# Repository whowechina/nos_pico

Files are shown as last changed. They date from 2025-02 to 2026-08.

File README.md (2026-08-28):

# Nos Pico - Nostalgia Style Mini Controller
[点这里可以切换到中文版](README_CN.md)

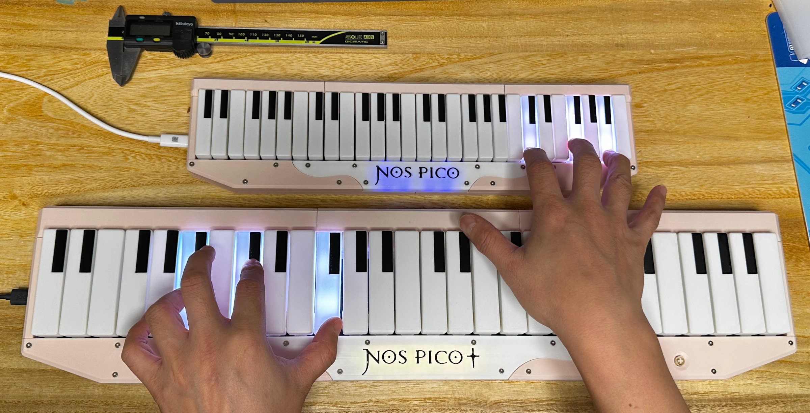
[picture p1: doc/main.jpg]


Currently there're two sizes of Nos Pico. Nos Pico is the small one, suitable for 15 to 17 inch monitors. Nos Pico+ is the larger one, suitable for 24 to 27 inch monitors. There're no differences except the size.

Features:
* All 3D printed parts.
* Velocity sensitive.
* RGB key lights.
* Works as MIDI keyboard.
* HID lights.
* 4 extra programmable buttons.

Thanks to many respectful guys/companies who made their tools or materials free or open source (KiCad, OnShape, InkScape, Raspberry things).

Special thanks to community projects and developers.
And also these projects:
* RP_Silicon_KiCad: https://github.com/HeadBoffin/RP_Silicon_KiCad
* Type-C: https://github.com/ai03-2725/Type-C.pretty

## My Other Projects
You can check out my other cool projects.

               


* Popn Pico: https://github.com/whowechina/popn_pico
* IIDX Pico: https://github.com/whowechina/iidx_pico
* Chu Pico: https://github.com/whowechina/chu_pico
* Mai Pico: https://github.com/whowechina/mai_pico
* Diva Pico: https://github.com/whowechina/diva_pico
* AIC Pico: https://github.com/whowechina/aic_pico
* Groove Pico: https://github.com/whowechina/groove_pico
* Geki Pico: https://github.com/whowechina/geki_pico
* Musec Pico: https://github.com/whowechina/musec_pico
* Ju Pico: https://github.com/whowechina/ju_pico
* Bishi Pico: https://github.com/whowechina/bishi_pico
* Nos Pico: https://github.com/whowechina/nos_pico
* Voltex Pico: https://github.com/whowechina/voltex_pico
* Chord Pico: https://github.com/whowechina/chord_pico
* Dance Pico: https://github.com/whowechina/dance_pico
* Arcade Pico: https://github.com/whowechina/arcade_pico

## **Disclaimer** ##
I made this project in my personal time with no financial benefit or sponsorship. I will continue to improve the project. I have done my best to ensure that everything is accurate and functional, there's always a chance that mistakes may occur. I cannot be held responsible for any loss of your time or money that may result from using this open source project. Thank you for your understanding.

## About the License
It's CC-NC. So DIY for yourself and for your friend, don't make money from it. And plagiarism that doesn’t even dare to mention the original author is not acceptable. Please note that pooling orders and group buying for raw materials is acceptable.Selling any leftover components at cost (without profit) is also acceptable.

If you're interested in buying from me, or for commercial use, please contact me (Discord, QQ group, Goofish).
* My Discord Invitation: https://discord.gg/M8f2PPQFEA
* QQ Group: 854535476
* Goofish: whowe12345

## HOW TO BUILD
### PCB and Components
* Go JLCPCB or any PCB vendor you like, make order with the gerber zip files (latest `Production\PCB\nos_pico_xxx.zip` for Nos Pico, or `Production\PCB\nos_plus_xxx.zip` for Nos Pico+), regular FR-4 board, black color, **1.6mm** thickness.

* 1x Rasberry Pico Pi Pico or pin-to-pin compatible clones, those with type-C port are strongly recommended.  
  https://www.raspberrypi.com/products/raspberry-pi-pico
* 1x USB Type-C socket (918-418K2023S40001 or KH-TYPE-C-16P)

* 1x ADG732BSUZ (TQFP48) analog multiplexer.  
  https://www.analog.com/en/products/adg732.html
* 1x MBR120VLSFT1G Schottky diode (SOD-123), or any SOD-123 **Schottky** diode with 1A or more current rating.
* 20x to 30x 0603 0.1uF (0.1~1uF all fine) capacitors.
* 3x 0603 5.1kohm resistors, 2 for USB and 1 for signal divider.
* 1x 0603 2kohm resistor for signal divider.
* 28x SS49E linear Hall effect sensors (SOT23).
* 1x Small 3V to 5V DC-DC step up or up-down converter. Make sure its output is 5V and input range covers 3.3V. If the one you get has different pinout, you need to hand wire it. If you don't see the footprint in the PCB, that means it's removed from newer revisions.  
  https://www.dfrobot.com/product-1766.html

* for Nos Pico only:
  * 56x WS2812B-4020 RGB LEDs (side facing)
  * 6x WS2812B-3528 RGB LEDs.
  * 4x HDK KSMC614A or Alps SKRGASD010 switches (6mm\*6mm\*9.5mm).  
    https://www.hdk.co.jp/pdf/spj/spj_ksmc614a.pdf  
    https://www.mouser.com/datasheet/2/15/alps_s_a0002902192_1-2258679.pdf
    
* for Nos Pico+ only:
  * 62x WS2812B-3528 RGB LEDs.
  * 4x Kailh Box Cream Pro switches.  
    https://www.kailh.net/products/kailh-box-cream-pro-switch-set

* Note: in newer revisions, the DC/DC is removed, use the following components instead.
  * 1x TPS7A2042PDBVR (4.2V) or LP5907MFX-4.5 (4.5V) LDO (SOT23-5), (U7).  
    https://www.ti.com/product/TPS7A20/part-details/TPS7A2042PDBVR
  * 1x LM4040 3.0V Shunt Voltage Reference, in SOT23-3 (U6). There're many models; make sure it's 3.0V and in an SOT23-3 package.
  * R1 and R2 are 2Kohm and 5.1Kohm 0603 resistors, respectively.

* This is how Nos Pico looks after soldering.  
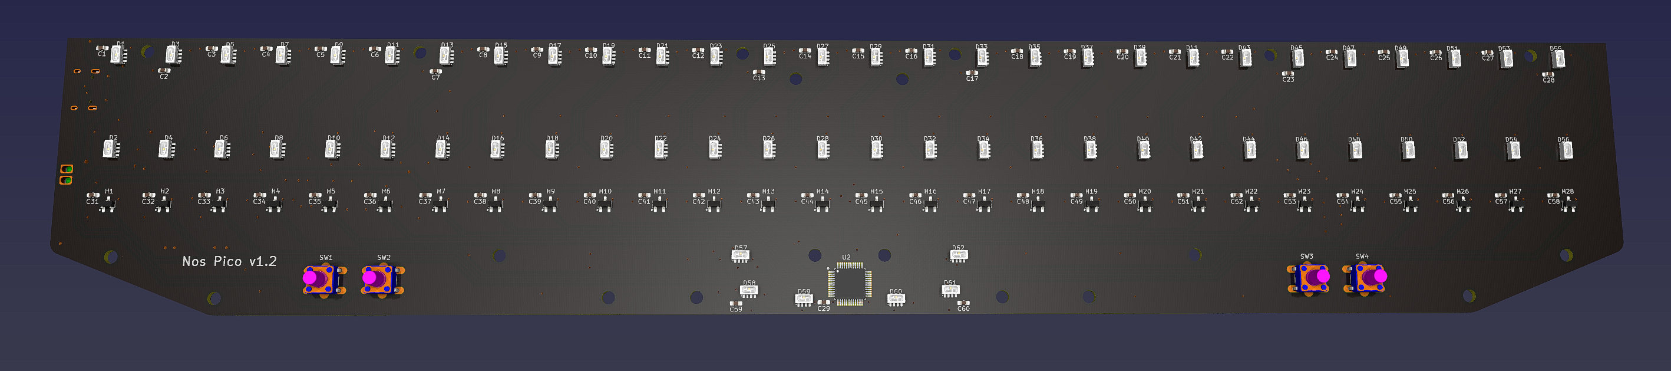
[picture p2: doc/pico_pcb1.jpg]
    
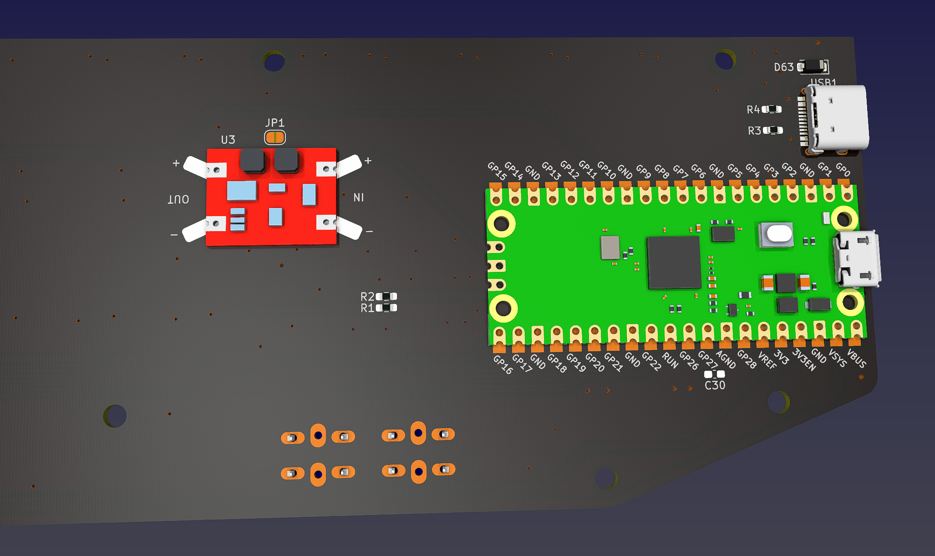
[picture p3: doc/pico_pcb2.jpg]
  

* This is how Nos Pico+ looks after soldering.  
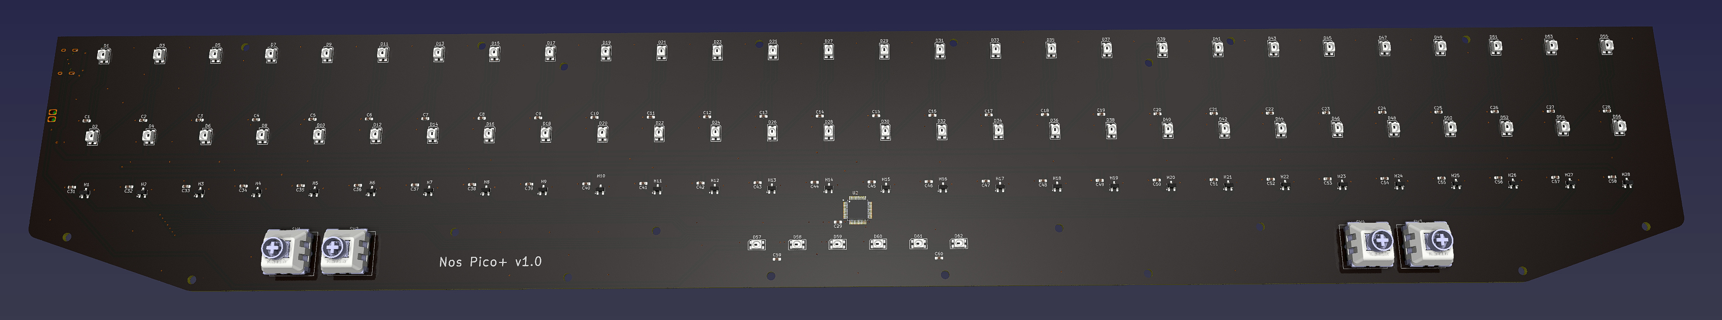
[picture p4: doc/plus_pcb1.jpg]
    
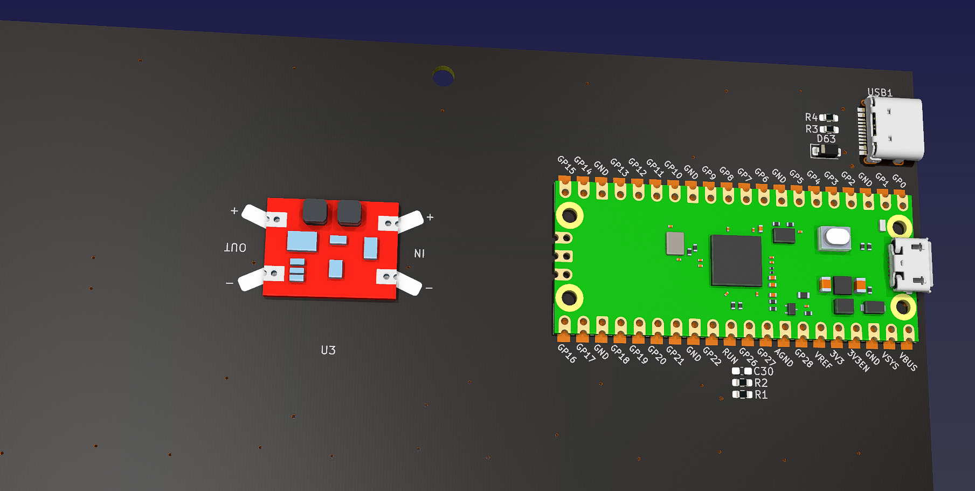
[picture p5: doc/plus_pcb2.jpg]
  

### Notes
1. About the 2 USB holes, you decide whether to solder them or not.   
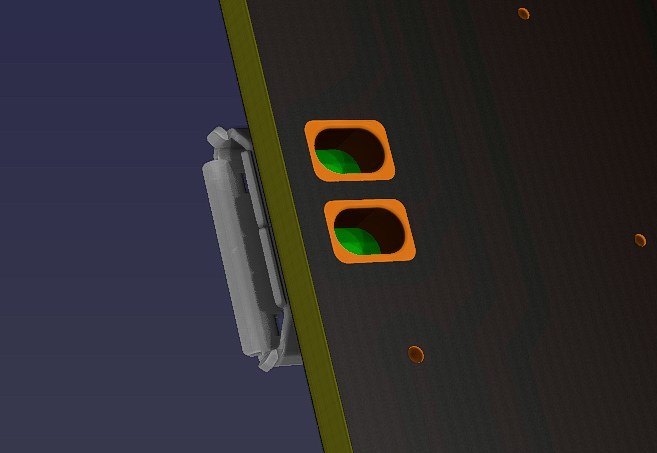
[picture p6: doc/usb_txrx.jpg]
   

   * If you solder these 2 hole pins.
     * Pros: ether USB ports can be used for host communication; if your pico has a micro USB port, now you'll have a Type-C port and a micro USB port.
     * Cons: if one port is for host communication, the other port can use for power supply, but only from power bank or charger, not from a USB data port.

   * Or you don't solder them (and also better use thin tape to cover the pins on Pi Pico).
     * Pros: only the port from Pi Pico can be used for host communication, the other port can only be used for power supply.
     * Cons: the power supply port can connect to any USB port, inluding USB data ports, power banks or chargers.

2. There're so many capacitors for de-coupling. You don't need to solder them all. You can solder some of them, just distribute them evenly. The one near the multiplexer is a must.

3. Leave C30 un-soldered.

### Test the PCB
* You can test the PCB now, put the firmware in.
* Very likely all key LEDs will light up in white.
* Logo LEDs will slowly change color.
* Nos Pico should be recognized as a USB HID device, here's the test page.  
  https://greggman.github.io/html5-gamepad-test/
* The test page responds to the 4 button switches.
* Use the terminal tool to connect to Nos Pico's command line interface.
  https://googlechromelabs.github.io/serial-terminal/
* Keep the PCB away from magnetic field, such as speakers or motors and execute `calibrate origin`. All values should be similar and near 2200.
* If you notice strange values, you need to check the soldering of the muxiplexer and corresponding hall effect sensor.

### 3D Printing
#### Printing parameters  
* PLA or PETG.
* Layer height: 0.2mm
* Wall: 2 to 3.
* Support: No, unless explicitly mentioned.
* Files are always in milimeter unit, not inch.

#### Parts
* All files are in `Production\3DPrint` folder.
* File names started with `Nos Pico -` are for Nos Pico, and `Nos Pico+ -` are for Nos Pico+.

* Keys: `Key.3mf`. Print 28 keys, 8 all-white, and 20 white-with-black tops (with "black key"). You need multi-color printing for the keys, or you need to manually paint the black part.  
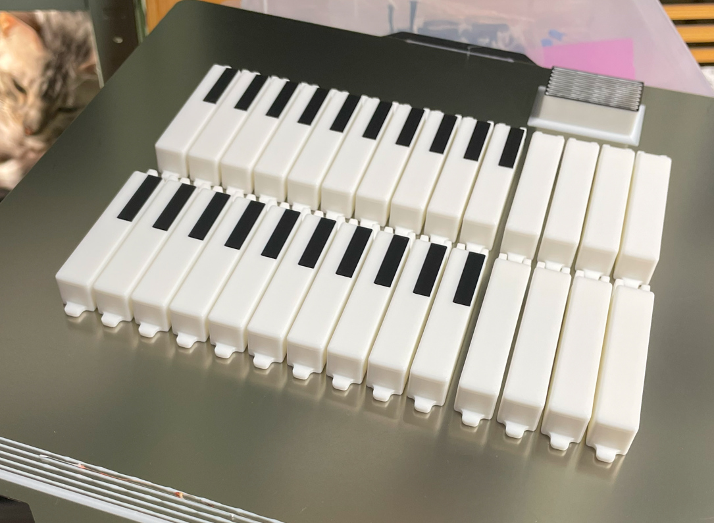
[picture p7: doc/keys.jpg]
  
* Base: `Base_*.stl`, all in light apricot color.
* Rear: `Rear_*.stl`, all in light apricot color. Make the side with the screws as the bottom and **enable support**.
* Support: `Support_*.stl`, Left and Right are in light apricot color and Center is in white color.
* Panel: `Panel_*.stl`, Left and Right are in light apricot color. The Center is in white color with the black logo on top. You can use multi-color to print it or paint it manually.

### Assembly
#### Other components needed
Please note that the quantities of the screws are approximate.

* 10x M3\*6mm screws for the PCB to the base parts.
* 20x M3\*8mm screws for support parts to the base parts.
* 16x M3\*8mm screws for rear parts to the base parts.
* 20x M2\*8mm countersunk screws for the panels to the support parts.
* Some 2.5mm~3mm thick self-adhesive foam tape (Poron or EVA).
* Some 1mm~1.5mm thick self-adhesive foam tape (Poron or EVA).

* 28x 0.4\*5\*10\*6N (0.4mm wire diameter, 5mm outer diameter, 10mm free length, 6 turns) springs.
* Some white silicone adhesive, such as K-704 silicone industrial adhesive.

* Some 10mm diameter silicone self-adhesive anti-slip pads.  

* For Nos Pico only.
  * 1x 2mm\*361mm stainless steel wire shaft.
  * 28x 2mm\*2mm axial magnetized cylinder magnets (2mm diameter, 2mm height).

* For Nos Pico+ only.
  * 1x 2mm\*573mm stainless steel wire shaft.
  * 28x 3mm\*2mm axial magnetized cylinder magnets (3mm diameter, 2mm height).

#### Steps
Please note that the pictures in this section are mixed with Nos Pico and Nos Pico+, some are even from prototype. But the assembly steps are the same. So ignore the differences in some details.

1. Use the M3\*6mm screws to fix the PCB to the base part.  
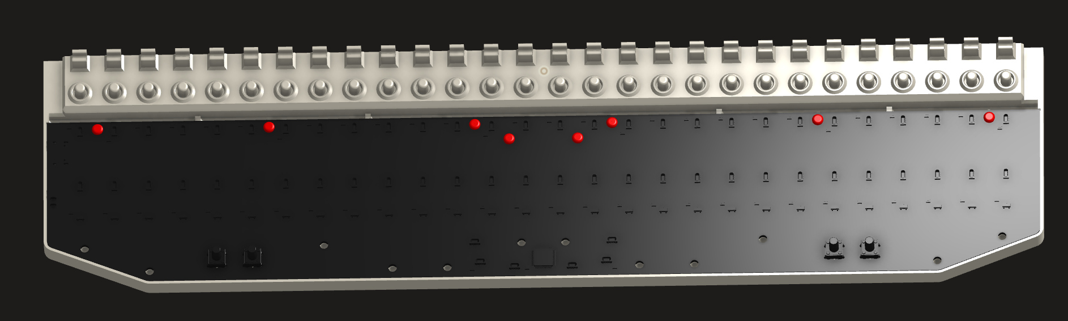
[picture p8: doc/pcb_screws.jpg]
   
2. Apply the 2.5mm thick foam tape on PCB, right below the hall effect sensors. It damps the key press noise. 3mm width is recommended for Nos Pico, and 5mm width is recommended for Nos Pico+.  
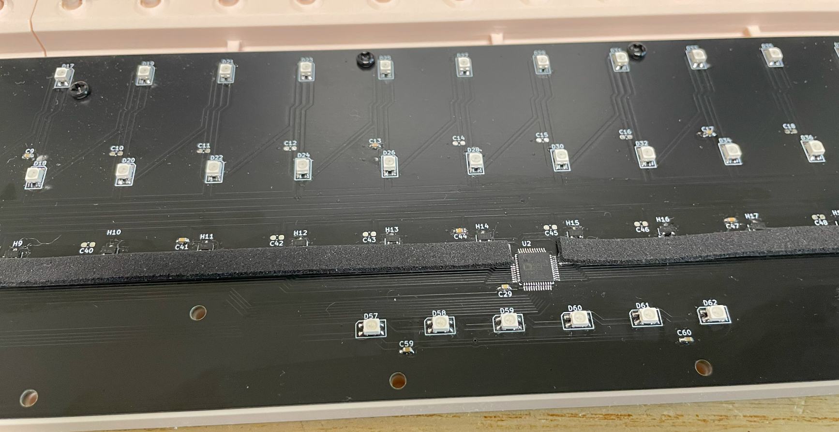
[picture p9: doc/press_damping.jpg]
   
3. Use the M3*8mm screws to fix the support parts to the base part.  
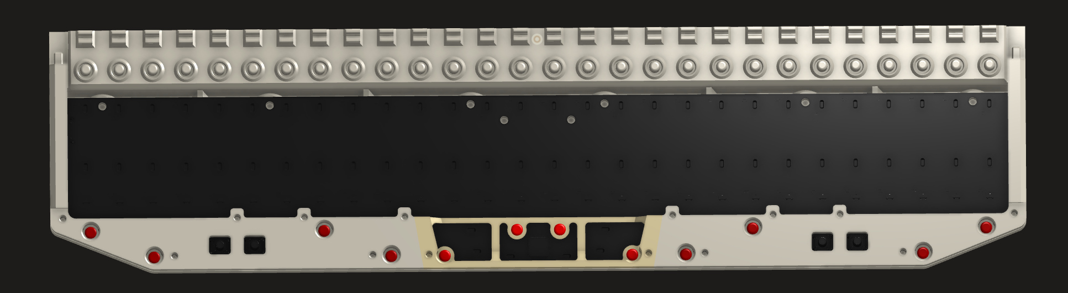
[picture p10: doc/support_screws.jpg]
   
4. Insert the steel shafts into keys and install them into the base parts. Please note the key arrangements.  
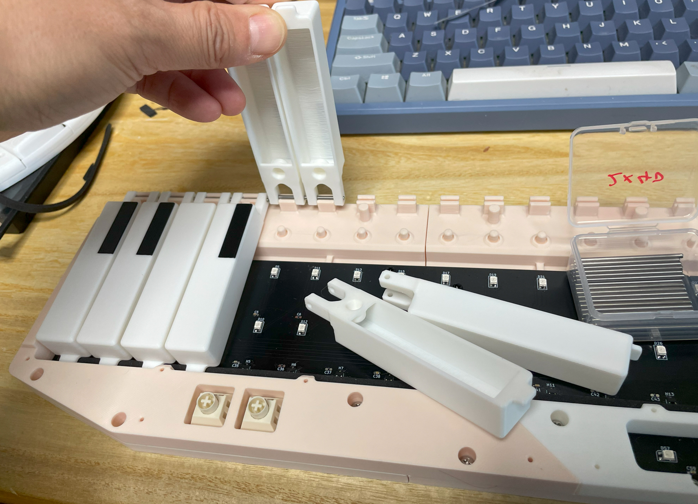
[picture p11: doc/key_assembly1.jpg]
     
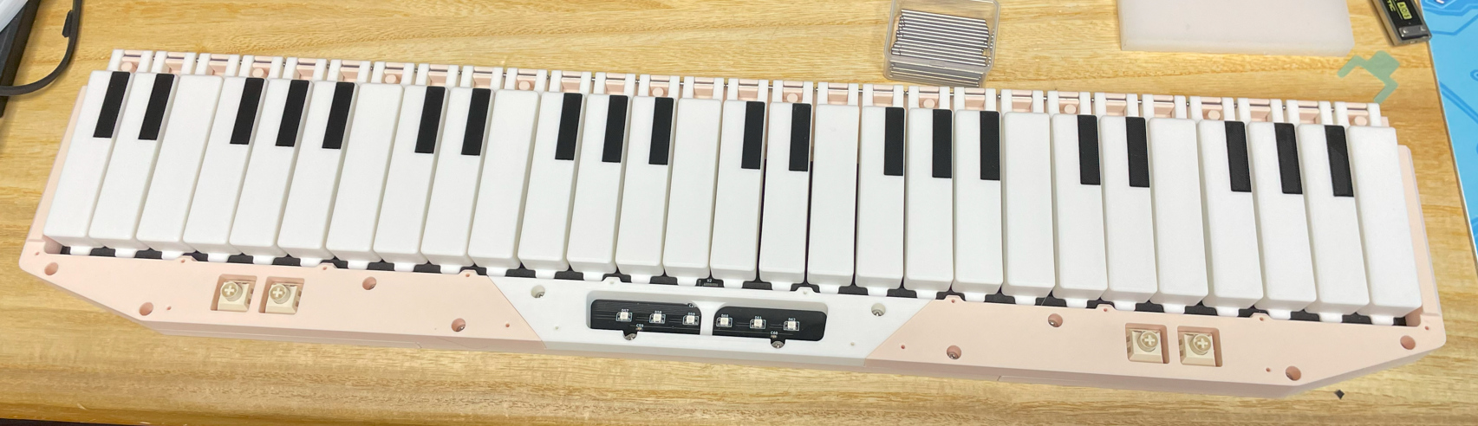
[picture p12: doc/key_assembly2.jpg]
   
5. Rotate the keys to the other side to insert the magnets into the keys. Cylinder magnets should be placed vertically. You need some glue or silicone adhesive to fix them in place.
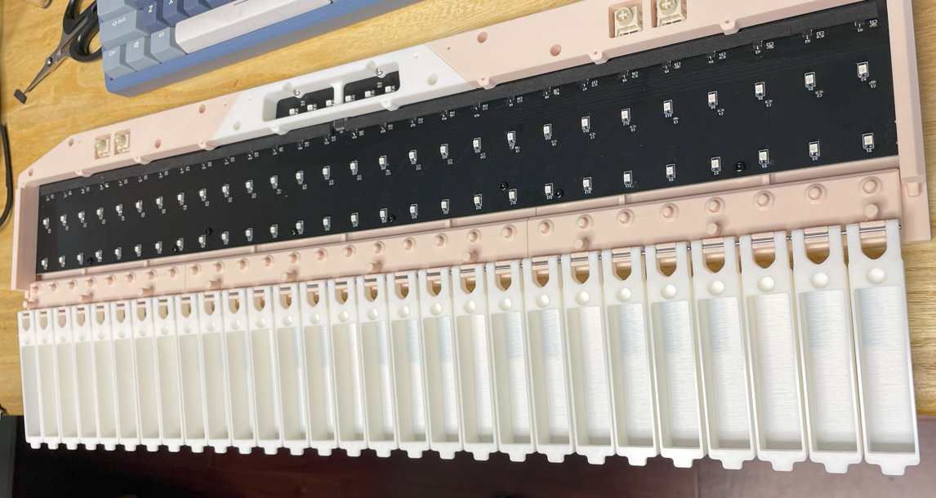
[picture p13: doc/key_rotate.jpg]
     
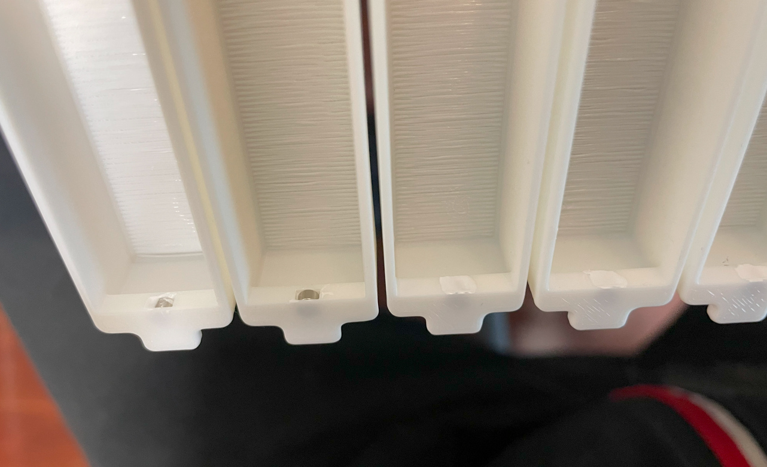
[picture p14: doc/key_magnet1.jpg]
     
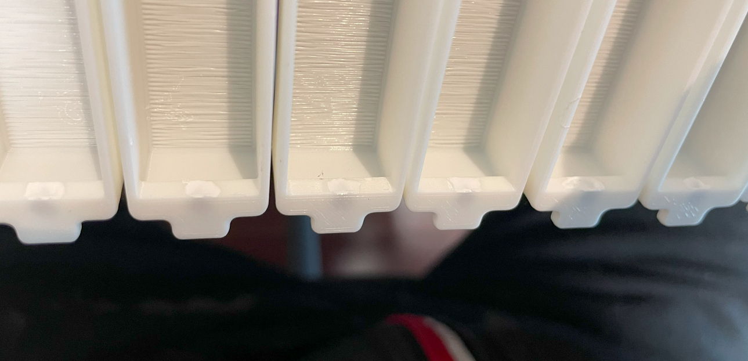
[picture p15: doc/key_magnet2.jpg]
   
6. Install the springs on the base parts, and rotate the keys onto them.
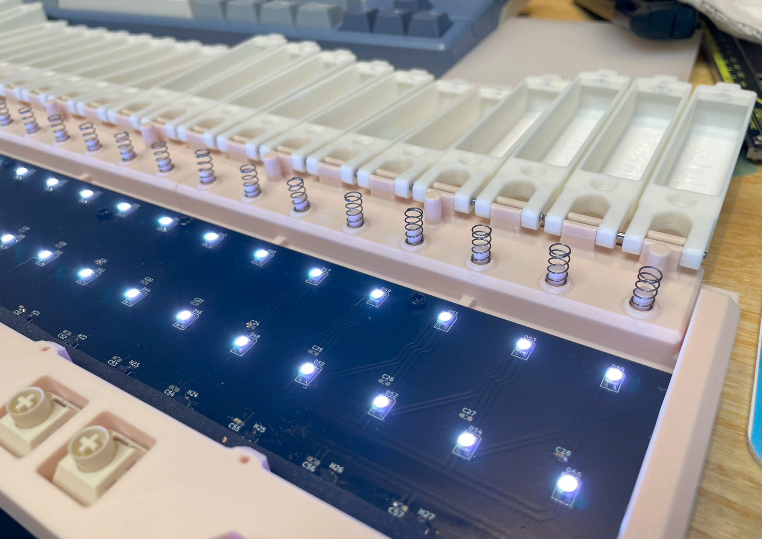
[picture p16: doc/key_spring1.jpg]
     
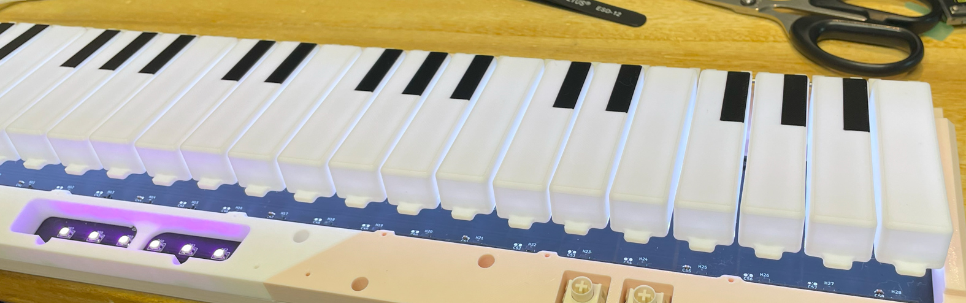
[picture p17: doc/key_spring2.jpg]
   
7. Now we temporarily calibrate and test the keys use `calibrate travel` command. Leave the keys un-pressed before executing the command, 1 second later, gently press down all the keys (not neccessarily all of them simultanously, just to cover them all). After calibration, keys are ready for play. You can use some MIDI software to test the keys. If all keys work fine, you can proceed to the next step. If not, you need to check the soldering of the hall effect sensors and the multiplexer.  
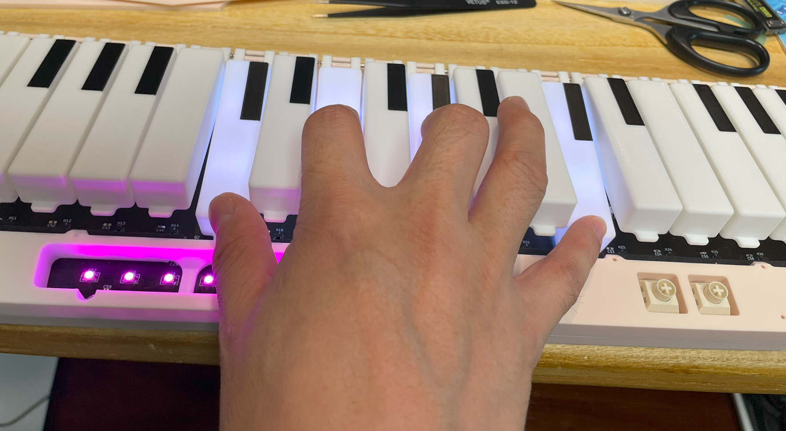
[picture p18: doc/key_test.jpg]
   
8. Apply the 1mm thick foam tape on the edge of the panel parts. It damps the key release noise.  
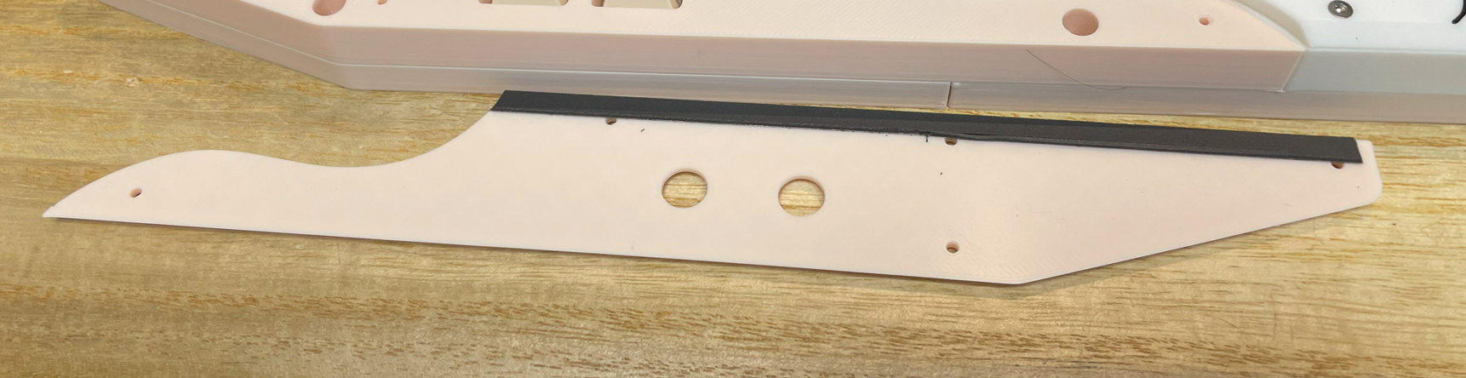
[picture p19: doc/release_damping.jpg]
   
9.  Use the M2*8mm countersunk screws to fix the panel parts to the support parts.  
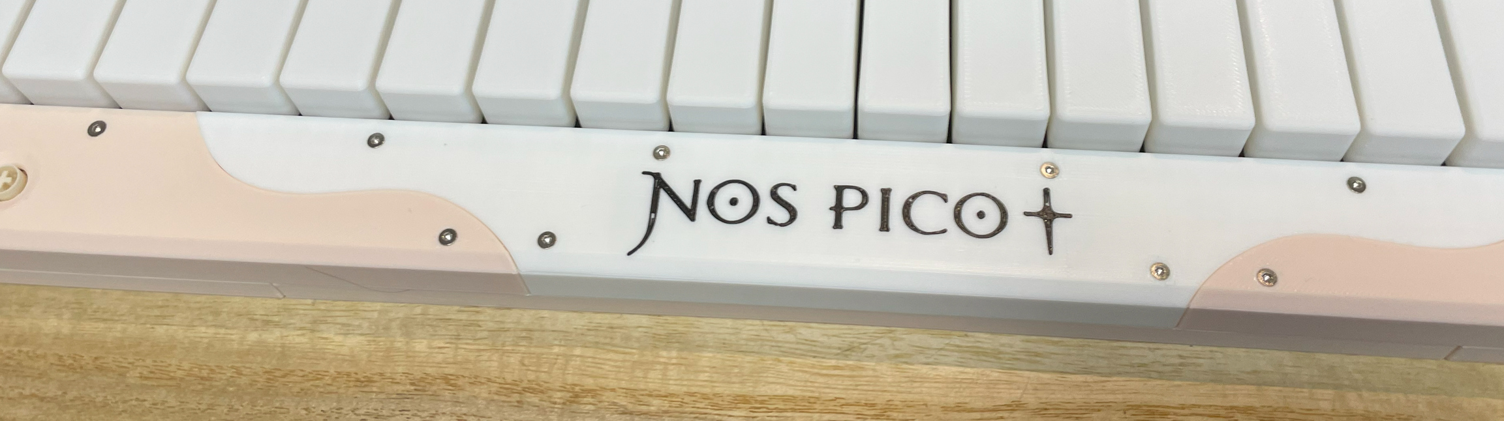
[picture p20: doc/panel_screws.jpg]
    
10. Use the M3*10mm screws to fix the rear parts to the base parts. Please note that left and right rear parts have a shaft limit slot, which is blocked by thin walls working as print support, you need to cut them open.  
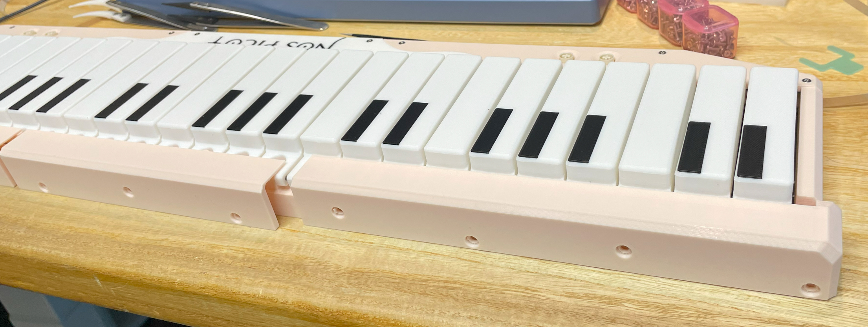
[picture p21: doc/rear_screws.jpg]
    
11. Now calibrate the key travel again use `calibrate travel` command, don't forget to gently press down all the keys 1 second after executing the command.
12. Apply the silicone self-adhesive anti-slip pads on the bottom of the base parts.  
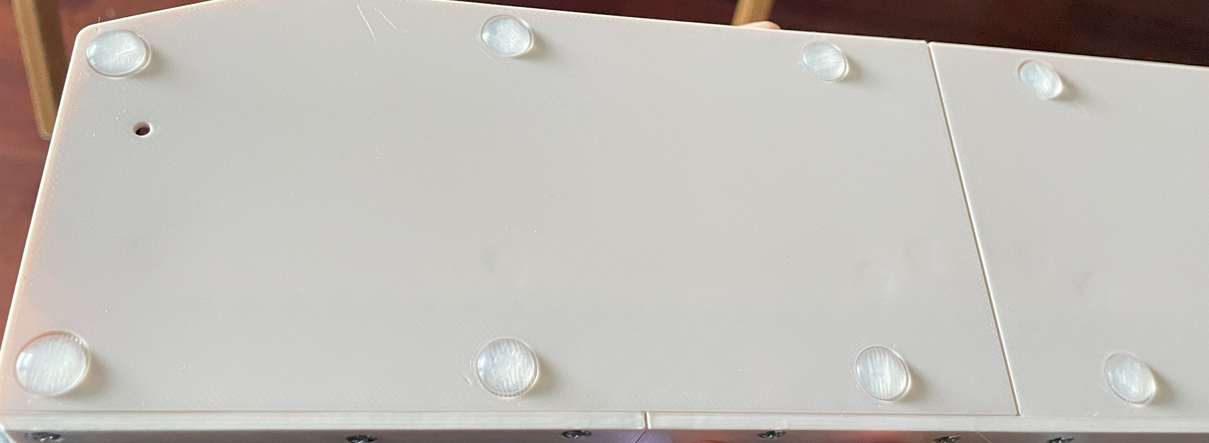
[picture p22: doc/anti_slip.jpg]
    
13. Congratulations, you finished!
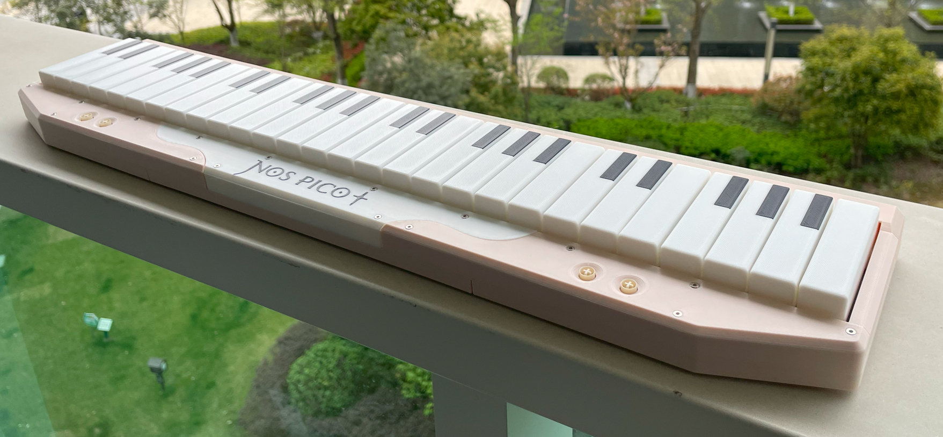
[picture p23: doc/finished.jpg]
    

#### Caution
* Don't use `calibrate origin` command after the assembly. It can only be used when there's no magnets installed.
* Screws are easy to break 3D printed parts. So don't screw them too fast or too tight. When you notice the resistance suddenly increases, stop immediately.

### Firmware
* UF2 file is in `Production\Firmware` folder.
* For the new build, hold the BOOTSEL button while connect the USB to a PC, there will be a disk named "RPI-RP2" showed up. Drag the UF2 firmware binary file into it. That's it. Note that there's a small hole on the bottom side of the Nos Pico, aligned with the BOOTSEL button.
* If it's already running Nos Pico firmware, you can either use "update" in command line or hold down left 2 buttons while connecting to USB to enter update mode.
* To access the command line, you can use this Web Serial Terminal to connect to the command line port of the controller. (Note: "?" is for help)  
  https://googlechromelabs.github.io/serial-terminal/

### Usage
* By default, it works as a MIDI keyboard. Just plug and play.
* You can change the report to HID buttons, or HID analog values (axis) with `hid *` command.
* You can change the key light mode using `light *` command.
* You can change the light brightness using `level <key|logo>` command.
* You can do live setting without the command line interface. Let's call the 4 auxilary keys are L1, L2, R1, R2. Pressing all of them at the same time will enter the live setting mode.
  * L1 and L2 are for navigating the setting items. The logo light shows current item. The items are:
    * Brightness for Piano Key Light
    * Brightness for Logo Light
    * Piano Key Light Mode (Off, Switch, Pressure, Velocity)
  * R1 is Cancel, R2 is Confirm.
  * The piano keys are for changing the values of the setting items.  

## CAD Source File
I'm using OnShape free subscription. It's powerful but it can't archive original designs to local, so I can only share the link here. STL/DXF/DWG files are exported from this online document.  
  https://cad.onshape.com/documents/0429d4b0d9d82f8289fdce7e/w/647e985c461e79dd4ff63d99/e/9dea2fe40b32c7a64632a585

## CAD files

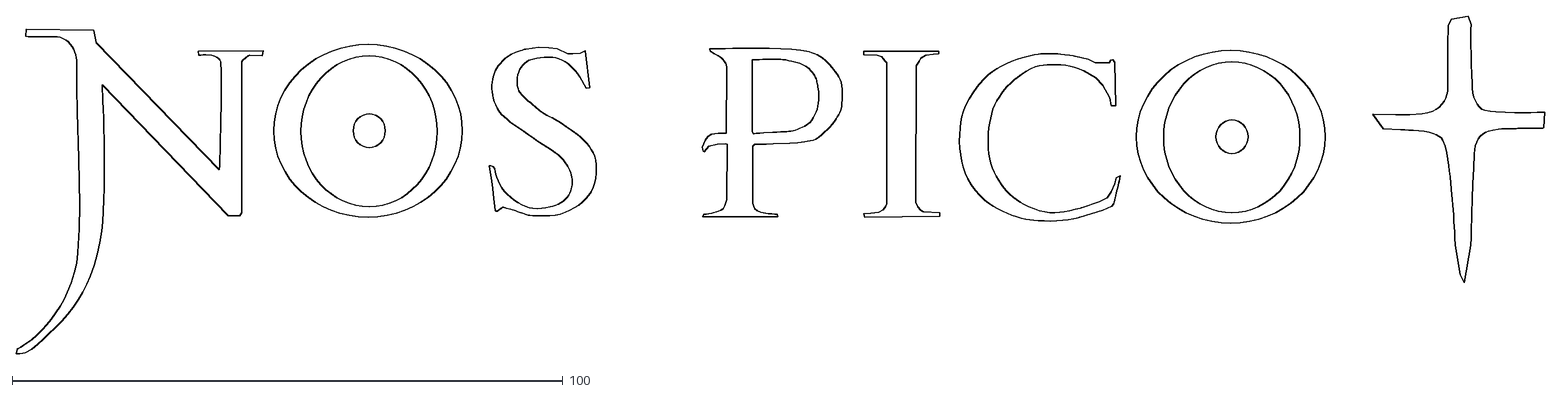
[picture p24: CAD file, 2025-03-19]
art/logo_nos_pico+.dxf
277.6 x 61.3

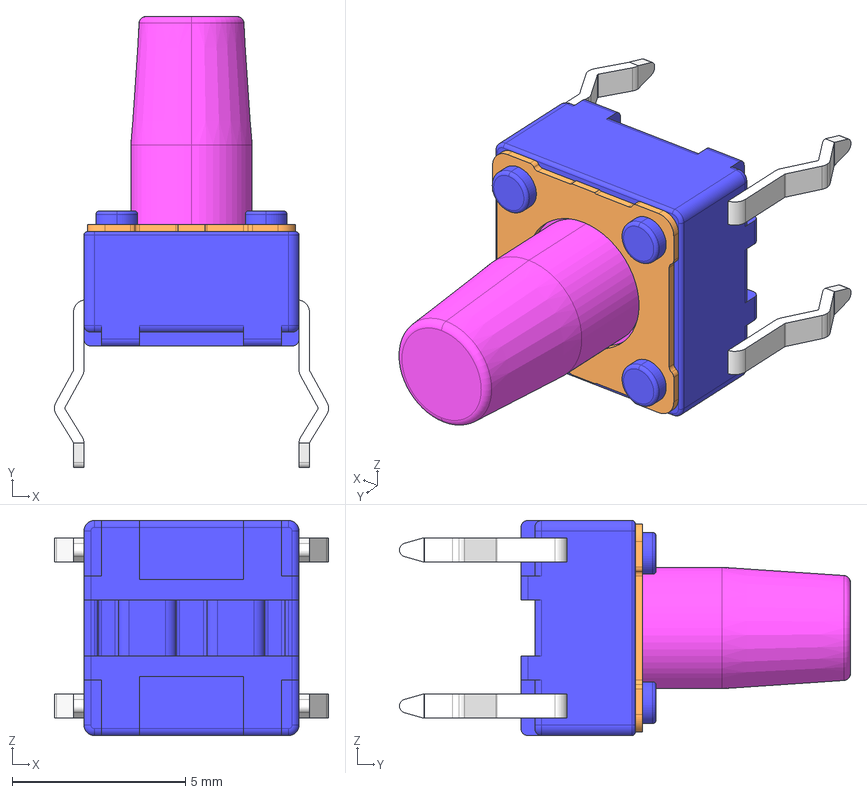
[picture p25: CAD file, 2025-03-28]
PCB/pico/3dmodels/skhhana010.stp
7.90 x 13.0 x 6.20 mm

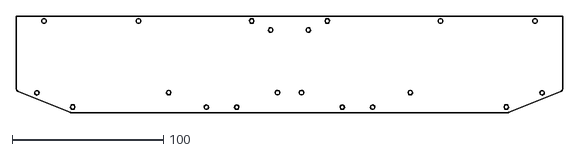
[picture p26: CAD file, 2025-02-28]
PCB/pico/Nos Pico - PCB.dxf
362.0 x 64.0

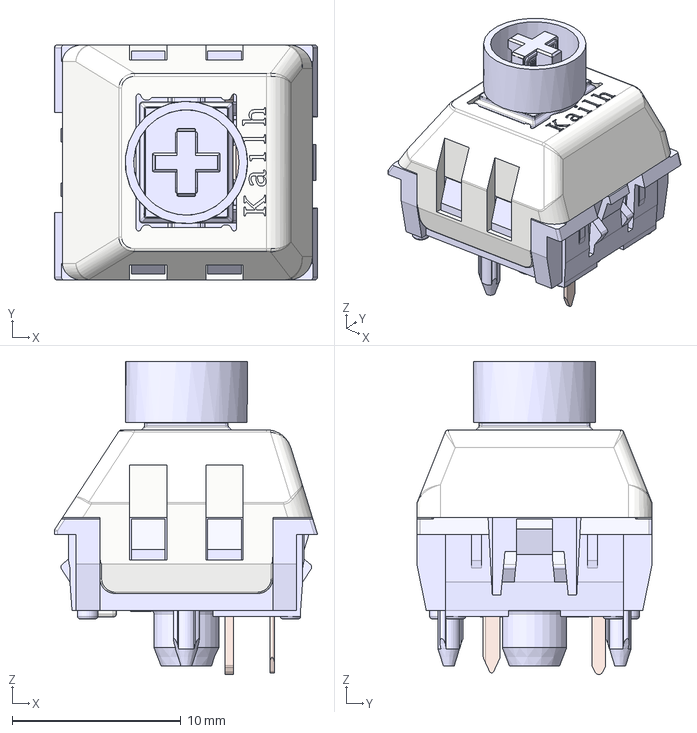
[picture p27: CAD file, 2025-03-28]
PCB/plus/3dmodels/Kailh_polia_mod.step
15.6 x 14.0 x 18.5 mm

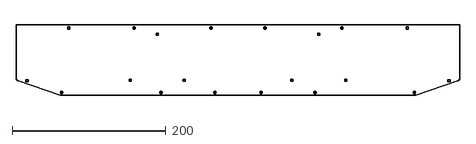
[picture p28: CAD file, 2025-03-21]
PCB/plus/Nos Plus.dxf
576.0 x 92.1

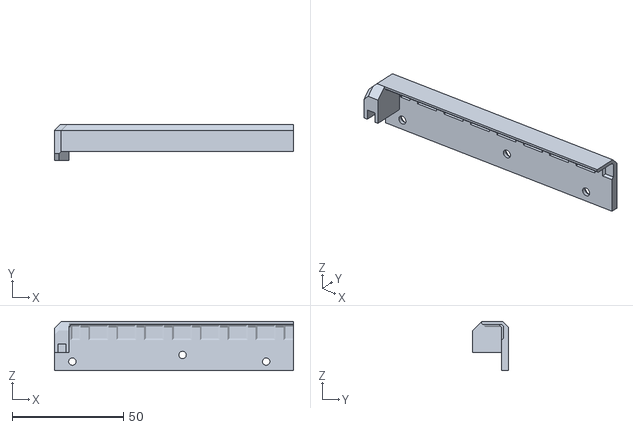
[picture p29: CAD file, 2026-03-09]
Production/3DPrint/Nos Pico - Rear Left.stl
107.2 x 16.0 x 22.0

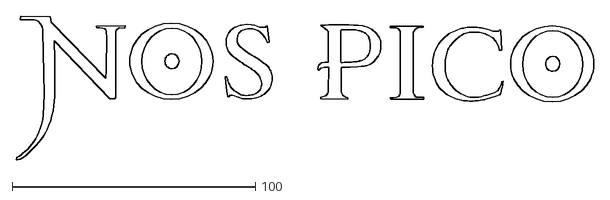
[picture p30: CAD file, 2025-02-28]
art/logo.dxf
237.7 x 59.0

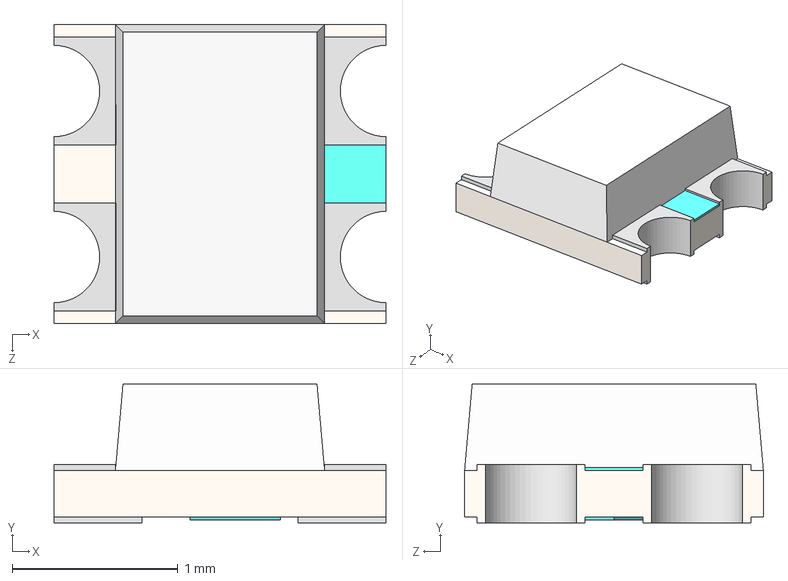
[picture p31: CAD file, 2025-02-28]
PCB/pico/3dmodels/WS2812-0807.STEP
2.00 x 0.835 x 1.80 mm

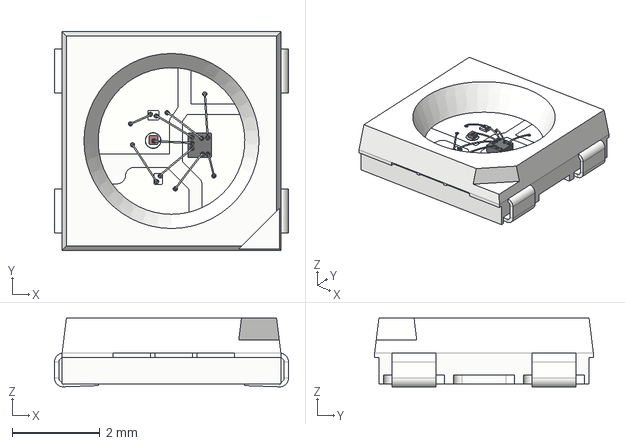
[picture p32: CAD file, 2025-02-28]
PCB/plus/3dmodels/WS2812B.step
5.35 x 5.00 x 1.57 mm

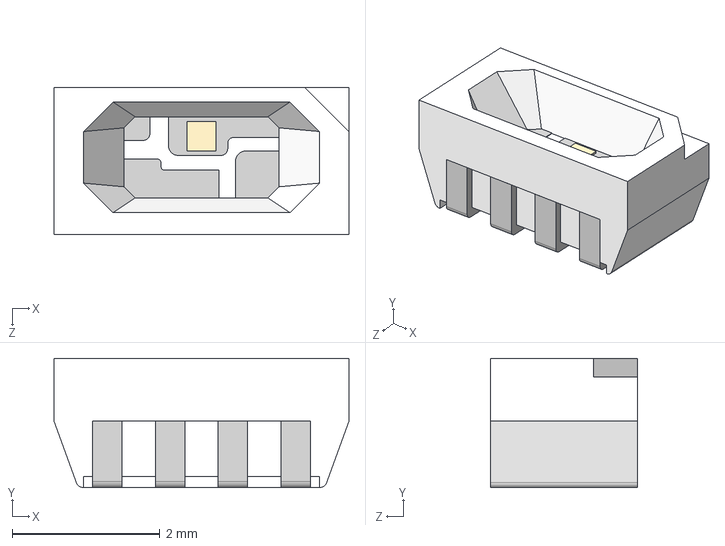
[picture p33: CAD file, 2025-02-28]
PCB/pico/3dmodels/User Library-WS2812-4020.step
4.00 x 1.75 x 2.00 mm

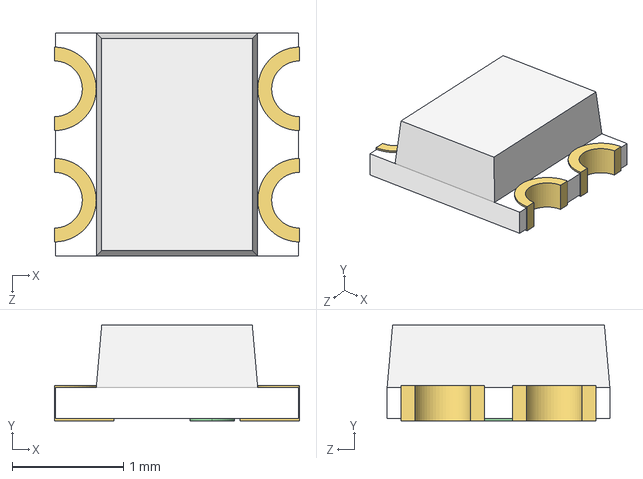
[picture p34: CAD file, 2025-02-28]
PCB/plus/3dmodels/WS2812-2020.STEP
2.20 x 0.86 x 2.00 mm

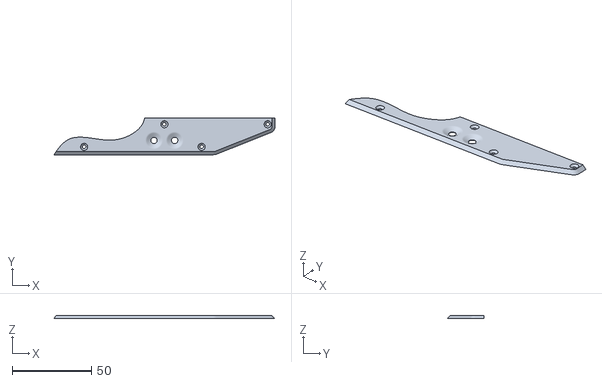
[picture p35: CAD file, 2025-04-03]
Production/3DPrint/Nos Pico - Panel Right.stl
139.2 x 23.0 x 2.00

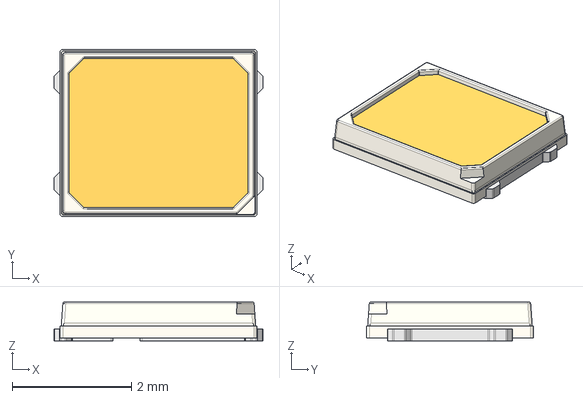
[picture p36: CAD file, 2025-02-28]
PCB/plus/3dmodels/J 2835.step
3.50 x 2.80 x 0.65 mm

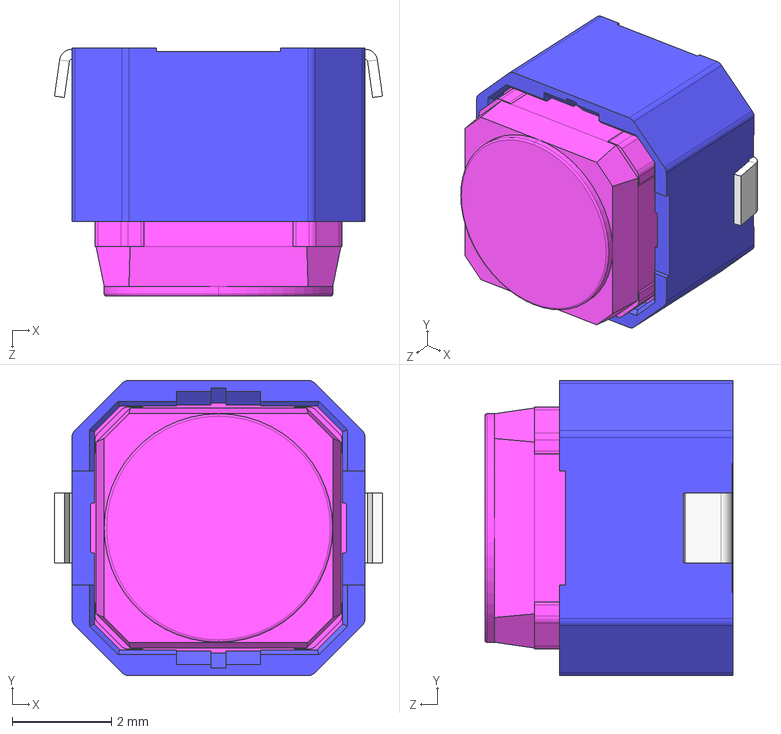
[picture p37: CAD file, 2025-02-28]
PCB/pico/3dmodels/SKPMAM.STEP
6.60 x 5.94 x 5.00 mm

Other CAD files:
Production/3DPrint/Nos Pico - Rear Right.stl
Production/3DPrint/Nos Pico - Panel Left.stl
PCB/pico/3dmodels/ADG732BSUZ.step
PCB/pico/3dmodels/EVQ-P1D05M.stp
PCB/pico/3dmodels/SKSTAAE010.STEP
PCB/pico/3dmodels/SMD WS2812B-3535.step
PCB/pico/3dmodels/User Library-WS2812-2020.step
PCB/plus/3dmodels/ADG732BSUZ.step
PCB/plus/3dmodels/EVQ-P1D05M.stp
PCB/plus/3dmodels/SKSTAAE010.STEP
PCB/plus/3dmodels/SMD WS2812B-3535.step
PCB/plus/3dmodels/User Library-WS2812-2020.step
Production/3DPrint/Nos Pico - Key.3mf
Production/3DPrint/Nos Pico - Panel Center.3mf
Production/3DPrint/Nos Pico - Rear Center.stl
Production/3DPrint/Nos Pico - Support Center.stl
Production/3DPrint/Nos Pico - Support Left.stl
Production/3DPrint/Nos Pico - Support Right.stl
Production/3DPrint/Nos Pico+ - Key.3mf
Production/3DPrint/Nos Pico+ - Panel Center.3mf
Production/3DPrint/Nos Pico+ - Panel Left.stl
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

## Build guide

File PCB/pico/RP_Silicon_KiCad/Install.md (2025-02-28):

# Install KiCad libraries

## Manage Symbol Libraries

Accessed from the Preferences menu, add a new line with the +, give it a name and use the folder icon to point to the directory/folder where you have KiCadLibraries.

Manage Symbol Libraries screen shot


## Manage Footprint Libraries

Ditto! Accessed from the Preferences menu, add a new line with the +, give it a name and use the folder icon to point to the directory/folder where you have KiCadLibraries.

Manage Footprint Libraries screen shot


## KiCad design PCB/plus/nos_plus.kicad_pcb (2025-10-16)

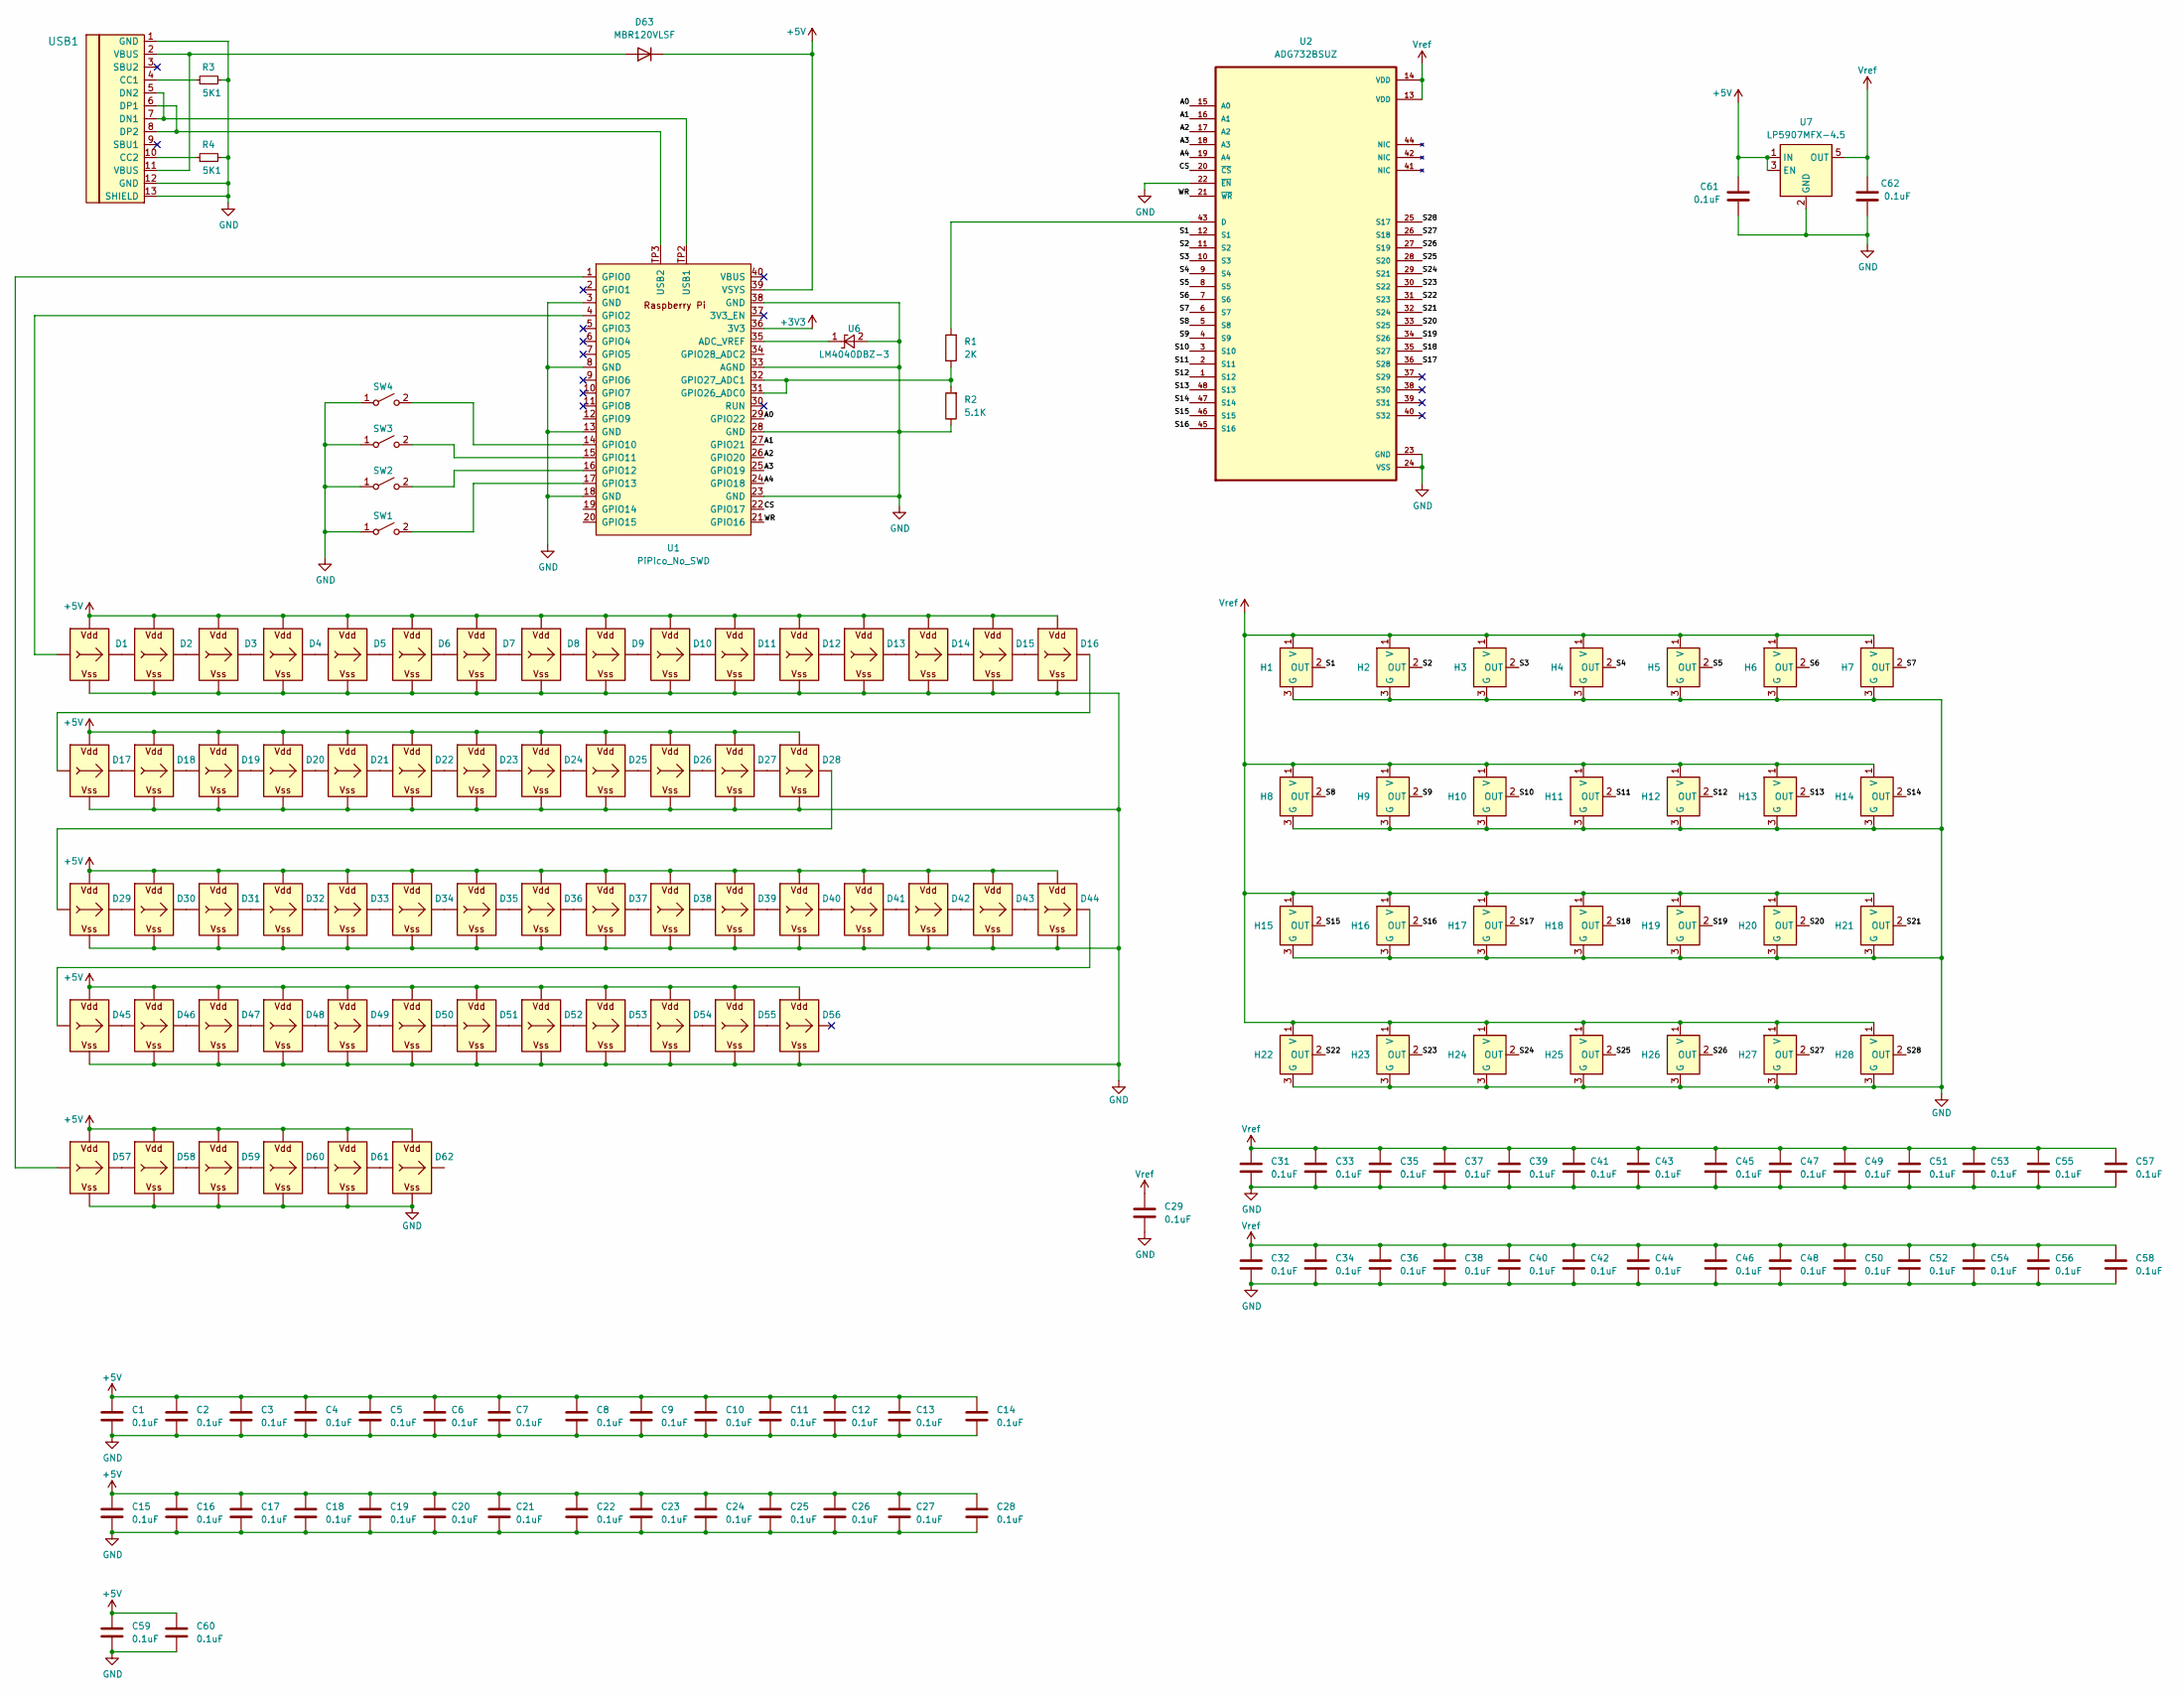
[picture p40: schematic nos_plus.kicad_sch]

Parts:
C1, C2, C3, C4, C5, C6, C7, C8, C9, C10, C11, C12, C13, C14, C15, C16, C17, C18, C19, C20, C21, C22, C23, C24, C25, C26, C27, C28, C29, C31, C32, C33, C34, C35, C36, C37, C38, C39, C40, C41, C42, C43, C44, C45, C46, C47, C48, C49, C50, C51, C52, C53, C54, C55, C56, C57, C58, C59, C60, C61, C62: 0.1uF; C_0603_1608Metric_Pad1.08x0.95mm_HandSolder
D1, D2, D3, D4, D5, D6, D7, D8, D9, D10, D11, D12, D13, D14, D15, D16, D17, D18, D19, D20, D21, D22, D23, D24, D25, D26, D27, D28, D29, D30, D31, D32, D33, D34, D35, D36, D37, D38, D39, D40, D41, D42, D43, D44, D45, D46, D47, D48, D49, D50, D51, D52, D53, D54, D55, D56, D57, D58, D59, D60, D61, D62: WS2812B_Unified; WS2812B-2835
D63: MBR120VLSF; D_SOD-123_LONG
H1, H2, H3, H4, H5, H6, H7, H8, H9, H10, H11, H12, H13, H14, H15, H16, H17, H18, H19, H20, H21, H22, H23, H24, H25, H26, H27, H28: SS49E_SOT23; SOT-23-FAT
R1: 2K; R_0603_1608Metric_Pad0.98x0.95mm_HandSolder
R2: 5.1K; R_0603_1608Metric_Pad0.98x0.95mm_HandSolder
R3, R4: 5K1; R_0603_1608Metric_Pad0.98x0.95mm_HandSolder; LCSC C23186
SW1, SW2, SW3, SW4: SW_SPST; SW_Choc_V1V2_Cherry_MX_LED
U1: PiPico_No_SWD; RPi_Pico_SMD_Pins_No_SWD
U2: ADG732BSUZ; QFP50P900X900X120-49N
U6: LM4040DBZ-3; SOT-23-FAT
U7: LP5907MFX-4.5; SOT-23-5
USB1: U262-161N-4BVC11; HRO-TYPE-C-31-M-12-Assembly; LCSC C319148

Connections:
+3V3: U1.36 (3V3)
+5V: C1.1, C2.1, C3.1, C4.1, C5.1, C6.1, C7.1, C8.1, C9.1, C10.1, C11.1, C12.1, C13.1, C14.1, C15.1, C16.1, C17.1, C18.1, C19.1, C20.1, C21.1, C22.1, C23.1, C24.1, C25.1, C26.1, C27.1, C28.1, C59.1, C60.1, C61.1, D1.V (VDD), D2.V (VDD), D3.V (VDD), D4.V (VDD), D5.V (VDD), D6.V (VDD), D7.V (VDD), D8.V (VDD), D9.V (VDD), D10.V (VDD), D11.V (VDD), D12.V (VDD), D13.V (VDD), D14.V (VDD), D15.V (VDD), D16.V (VDD), D17.V (VDD), D18.V (VDD), D19.V (VDD), D20.V (VDD), D21.V (VDD), D22.V (VDD), D23.V (VDD), D24.V (VDD), D25.V (VDD), D26.V (VDD), D27.V (VDD), D28.V (VDD), D29.V (VDD), D30.V (VDD), D31.V (VDD), D32.V (VDD), D33.V (VDD), D34.V (VDD), D35.V (VDD), D36.V (VDD), D37.V (VDD), D38.V (VDD), D39.V (VDD), D40.V (VDD), D41.V (VDD), D42.V (VDD), D43.V (VDD), D44.V (VDD), D45.V (VDD), D46.V (VDD), D47.V (VDD), D48.V (VDD), D49.V (VDD), D50.V (VDD), D51.V (VDD), D52.V (VDD), D53.V (VDD), D54.V (VDD), D55.V (VDD), D56.V (VDD), D57.V (VDD), D58.V (VDD), D59.V (VDD), D60.V (VDD), D61.V (VDD), D62.V (VDD), D63.1 (K), U1.39 (VSYS), U7.1 (IN), U7.3 (EN)
/A0: U1.29 (GPIO22), U2.15 (A0)
/A1: U1.27 (GPIO21), U2.16 (A1)
/A2: U1.26 (GPIO20), U2.17 (A2)
/A3: U1.25 (GPIO19), U2.18 (A3)
/A4: U1.24 (GPIO18), U2.19 (A4)
/CS: U1.22 (GPIO17), U2.20 (~CS)
/S1: H1.2 (OUT), U2.12 (S1)
/S2: H2.2 (OUT), U2.11 (S2)
/S3: H3.2 (OUT), U2.10 (S3)
/S4: H4.2 (OUT), U2.9 (S4)
/S5: H5.2 (OUT), U2.8 (S5)
/S6: H6.2 (OUT), U2.7 (S6)
/S7: H7.2 (OUT), U2.6 (S7)
/S8: H8.2 (OUT), U2.5 (S8)
/S9: H9.2 (OUT), U2.4 (S9)
/S10: H10.2 (OUT), U2.3 (S10)
/S11: H11.2 (OUT), U2.2 (S11)
/S12: H12.2 (OUT), U2.1 (S12)
/S13: H13.2 (OUT), U2.48 (S13)
/S14: H14.2 (OUT), U2.47 (S14)
/S15: H15.2 (OUT), U2.46 (S15)
/S16: H16.2 (OUT), U2.45 (S16)
/S17: H17.2 (OUT), U2.36 (S28)
/S18: H18.2 (OUT), U2.35 (S27)
/S19: H19.2 (OUT), U2.34 (S26)
/S20: H20.2 (OUT), U2.33 (S25)
/S21: H21.2 (OUT), U2.32 (S24)
/S22: H22.2 (OUT), U2.31 (S23)
/S23: H23.2 (OUT), U2.30 (S22)
/S24: H24.2 (OUT), U2.29 (S21)
/S25: H25.2 (OUT), U2.28 (S20)
/S26: H26.2 (OUT), U2.27 (S19)
/S27: H27.2 (OUT), U2.26 (S18)
/S28: H28.2 (OUT), U2.25 (S17)
/WR: U1.21 (GPIO16), U2.21 (~WR)
GND: C1.2, C2.2, C3.2, C4.2, C5.2, C6.2, C7.2, C8.2, C9.2, C10.2, C11.2, C12.2, C13.2, C14.2, C15.2, C16.2, C17.2, C18.2, C19.2, C20.2, C21.2, C22.2, C23.2, C24.2, C25.2, C26.2, C27.2, C28.2, C29.2, C31.2, C32.2, C33.2, C34.2, C35.2, C36.2, C37.2, C38.2, C39.2, C40.2, C41.2, C42.2, C43.2, C44.2, C45.2, C46.2, C47.2, C48.2, C49.2, C50.2, C51.2, C52.2, C53.2, C54.2, C55.2, C56.2, C57.2, C58.2, C59.2, C60.2, C61.2, C62.2, D1.G (VSS), D2.G (VSS), D3.G (VSS), D4.G (VSS), D5.G (VSS), D6.G (VSS), D7.G (VSS), D8.G (VSS), D9.G (VSS), D10.G (VSS), D11.G (VSS), D12.G (VSS), D13.G (VSS), D14.G (VSS), D15.G (VSS), D16.G (VSS), D17.G (VSS), D18.G (VSS), D19.G (VSS), D20.G (VSS), D21.G (VSS), D22.G (VSS), D23.G (VSS), D24.G (VSS), D25.G (VSS), D26.G (VSS), D27.G (VSS), D28.G (VSS), D29.G (VSS), D30.G (VSS), D31.G (VSS), D32.G (VSS), D33.G (VSS), D34.G (VSS), D35.G (VSS), D36.G (VSS), D37.G (VSS), D38.G (VSS), D39.G (VSS), D40.G (VSS), D41.G (VSS), D42.G (VSS), D43.G (VSS), D44.G (VSS), D45.G (VSS), D46.G (VSS), D47.G (VSS), D48.G (VSS), D49.G (VSS), D50.G (VSS), D51.G (VSS), D52.G (VSS), D53.G (VSS), D54.G (VSS), D55.G (VSS), D56.G (VSS), D57.G (VSS), D58.G (VSS), D59.G (VSS), D60.G (VSS), D61.G (VSS), D62.G (VSS), H1.3 (G), H2.3 (G), H3.3 (G), H4.3 (G), H5.3 (G), H6.3 (G), H7.3 (G), H8.3 (G), H9.3 (G), H10.3 (G), H11.3 (G), H12.3 (G), H13.3 (G), H14.3 (G), H15.3 (G), H16.3 (G), H17.3 (G), H18.3 (G), H19.3 (G), H20.3 (G), H21.3 (G), H22.3 (G), H23.3 (G), H24.3 (G), H25.3 (G), H26.3 (G), H27.3 (G), H28.3 (G), R2.1, R3.2, R4.2, SW1.1 (A), SW2.1 (A), SW3.1 (A), SW4.1 (A), U1.3 (GND), U1.8 (GND), U1.13 (GND), U1.18 (GND), U1.23 (GND), U1.28 (GND), U1.33 (AGND), U1.38 (GND), U2.22 (~EN), U2.23 (GND), U2.24 (VSS), U6.2 (A), U7.2 (GND), USB1.1 (GND), USB1.12 (GND), USB1.13 (SHIELD)
unnamed: D1.I (In), U1.4 (GPIO2)
unnamed: D1.O (Out), D2.I (In)
unnamed: D2.O (Out), D3.I (In)
unnamed: D3.O (Out), D4.I (In)
unnamed: D4.O (Out), D5.I (In)
unnamed: D5.O (Out), D6.I (In)
unnamed: D6.O (Out), D7.I (In)
unnamed: D7.O (Out), D8.I (In)
unnamed: D8.O (Out), D9.I (In)
unnamed: D9.O (Out), D10.I (In)
unnamed: D10.O (Out), D11.I (In)
unnamed: D11.O (Out), D12.I (In)
unnamed: D12.O (Out), D13.I (In)
unnamed: D13.O (Out), D14.I (In)
unnamed: D14.O (Out), D15.I (In)
unnamed: D15.O (Out), D16.I (In)
unnamed: D16.O (Out), D17.I (In)
unnamed: D17.O (Out), D18.I (In)
unnamed: D18.O (Out), D19.I (In)
unnamed: D19.O (Out), D20.I (In)
unnamed: D20.O (Out), D21.I (In)
unnamed: D21.O (Out), D22.I (In)
unnamed: D22.O (Out), D23.I (In)
unnamed: D23.O (Out), D24.I (In)
unnamed: D24.O (Out), D25.I (In)
unnamed: D25.O (Out), D26.I (In)
unnamed: D26.O (Out), D27.I (In)
unnamed: D27.O (Out), D28.I (In)
unnamed: D28.O (Out), D29.I (In)
unnamed: D29.O (Out), D30.I (In)
unnamed: D30.O (Out), D31.I (In)
unnamed: D31.O (Out), D32.I (In)
unnamed: D32.O (Out), D33.I (In)
unnamed: D33.O (Out), D34.I (In)
unnamed: D34.O (Out), D35.I (In)
unnamed: D35.O (Out), D36.I (In)
unnamed: D36.O (Out), D37.I (In)
unnamed: D37.O (Out), D38.I (In)
unnamed: D38.O (Out), D39.I (In)
unnamed: D39.O (Out), D40.I (In)
unnamed: D40.O (Out), D41.I (In)
unnamed: D41.O (Out), D42.I (In)
unnamed: D42.O (Out), D43.I (In)
unnamed: D43.O (Out), D44.I (In)
unnamed: D44.O (Out), D45.I (In)
unnamed: D45.O (Out), D46.I (In)
unnamed: D46.O (Out), D47.I (In)
unnamed: D47.O (Out), D48.I (In)
unnamed: D48.O (Out), D49.I (In)
unnamed: D49.O (Out), D50.I (In)
unnamed: D50.O (Out), D51.I (In)
unnamed: D51.O (Out), D52.I (In)
unnamed: D52.O (Out), D53.I (In)
unnamed: D53.O (Out), D54.I (In)
unnamed: D54.O (Out), D55.I (In)
unnamed: D55.O (Out), D56.I (In)
unnamed: D57.I (In), U1.1 (GPIO0)
unnamed: D57.O (Out), D58.I (In)
unnamed: D58.O (Out), D59.I (In)
unnamed: D59.O (Out), D60.I (In)
unnamed: D60.O (Out), D61.I (In)
unnamed: D61.O (Out), D62.I (In)
unnamed: D63.2 (A), USB1.2 (VBUS), USB1.11 (VBUS)
unnamed: SW1.2 (B), U1.17 (GPIO13)
unnamed: SW2.2 (B), U1.16 (GPIO12)
unnamed: SW3.2 (B), U1.15 (GPIO11)
unnamed: SW4.2 (B), U1.14 (GPIO10)
unnamed: U1.35 (ADC_VREF), U6.1 (K)
unnamed: R1.1, R2.2, U1.31 (GPIO26_ADC0), U1.32 (GPIO27_ADC1)
unnamed: U1.TP2 (USB1), USB1.5 (DN2), USB1.7 (DN1)
unnamed: U1.TP3 (USB2), USB1.6 (DP1), USB1.8 (DP2)
unnamed: R1.2, U2.43 (D)
unnamed: R3.1, USB1.4 (CC1)
unnamed: R4.1, USB1.10 (CC2)
Vref: C29.1, C31.1, C32.1, C33.1, C34.1, C35.1, C36.1, C37.1, C38.1, C39.1, C40.1, C41.1, C42.1, C43.1, C44.1, C45.1, C46.1, C47.1, C48.1, C49.1, C50.1, C51.1, C52.1, C53.1, C54.1, C55.1, C56.1, C57.1, C58.1, C62.1, H1.1 (V), H2.1 (V), H3.1 (V), H4.1 (V), H5.1 (V), H6.1 (V), H7.1 (V), H8.1 (V), H9.1 (V), H10.1 (V), H11.1 (V), H12.1 (V), H13.1 (V), H14.1 (V), H15.1 (V), H16.1 (V), H17.1 (V), H18.1 (V), H19.1 (V), H20.1 (V), H21.1 (V), H22.1 (V), H23.1 (V), H24.1 (V), H25.1 (V), H26.1 (V), H27.1 (V), H28.1 (V), U2.13 (VDD), U2.14 (VDD), U7.5 (OUT)

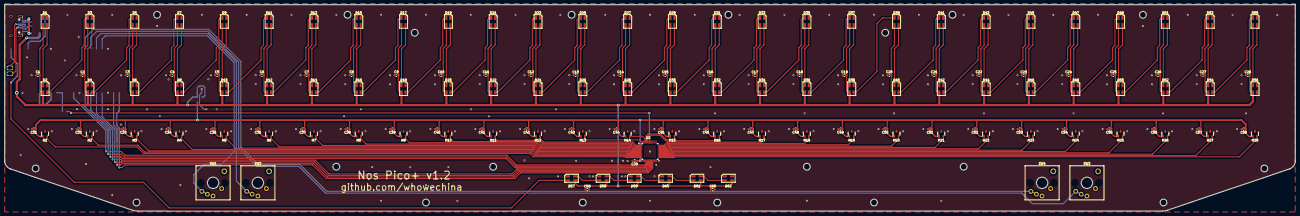
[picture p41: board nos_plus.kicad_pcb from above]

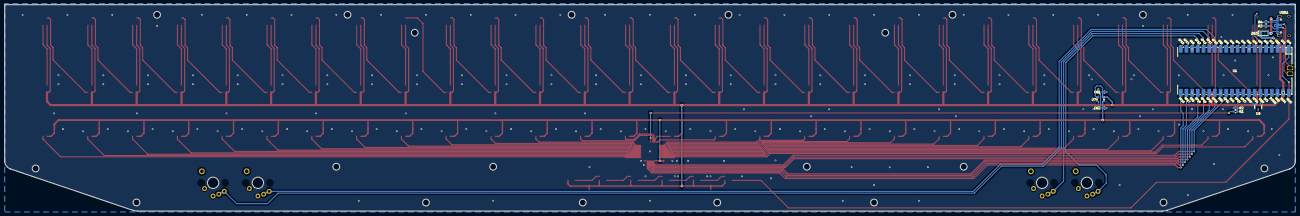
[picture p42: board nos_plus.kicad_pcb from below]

Board: 2 copper layers, 576.0 x 92.1 mm, 165 parts (11 on the bottom side), 112 nets.

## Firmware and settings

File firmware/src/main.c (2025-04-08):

/*
 * Controller Main
 * WHowe <github.com/whowechina>
 */

#include <stdlib.h>
#include <stdint.h>
#include <stdbool.h>

#include "pico/stdio.h"
#include "pico/stdlib.h"
#include "bsp/board.h"
#include "pico/multicore.h"
#include "pico/bootrom.h"

#include "hardware/clocks.h"
#include "hardware/gpio.h"
#include "hardware/sync.h"
#include "hardware/structs/ioqspi.h"
#include "hardware/structs/sio.h"

#include "tusb.h"
#include "usb_descriptors.h"

#include "board_defs.h"

#include "savedata.h"
#include "setup.h"
#include "config.h"
#include "cli.h"
#include "commands.h"

#include "light.h"
#include "hammer.h"
#include "button.h"

#define WHITE 0xffffff

static void run_lights()
{
    uint32_t phase = time_us_32() / 50000;
    light_set_logo(rgb32_from_hsv(phase, 255, 255), false);

    for (int i = 0; i < hammer_keynum(); i++) {
        uint32_t color = 0;
        if (nos_cfg->light.type == 1) {
            color = hammer_pressed(i) ? 0x808080 : 0;
        } else if (nos_cfg->light.type == 2) {
            color = rgb32_from_hsv(0, 0, 255 - hammer_analog(i));
        } else if (nos_cfg->light.type == 3) {
            if (hammer_pressed(i)) {
                uint16_t vel = hammer_velocity(i);
                if (vel > 254) {
                    vel = 254;
                }
                color = rgb32_from_hsv(0, 0, vel + 1);
            }
        }
        light_set_key(i, color, false);
    }
}

static mutex_t core1_io_lock;
static void core1_loop()
{
    sleep_ms(500);
    while (1) {
        if (mutex_try_enter(&core1_io_lock, NULL)) {
            if (!setup_is_active()) {
                run_lights();
            }
            light_update();
            mutex_exit(&core1_io_lock);
        }
        cli_fps_count(1);
        sleep_us(700);
    }
}

struct __attribute__((packed)) {
    uint32_t buttons;
    uint8_t analog[28];
} hid_report, old_hid_report;

static void hid_update()
{
    memset(&hid_report, 0, sizeof(hid_report));

    if (nos_cfg->hid.button) {
        for (int i = 0; i < hammer_keynum(); i++){
            hid_report.buttons |= hammer_pressed(i) ? (1 << i) : 0;
        }
    }

    hid_report.buttons |= button_read() << 28;

    for (int i = 0; i < hammer_keynum(); i++) {
        hid_report.analog[i] = nos_cfg->hid.analog ? hammer_analog(i) : 127;
    }

    if (!tud_hid_ready()) {
        return;
    }
    
    if (memcmp(&hid_report, &old_hid_report, sizeof(hid_report)) == 0) {
        return;
    }

    if (tud_hid_report(REPORT_ID_JOYSTICK, &hid_report, sizeof(hid_report))) {
        old_hid_report = hid_report;
    }
}

static void proc_midi()
{
    if (!nos_cfg->hid.midi) {
        return;
    }

    static uint8_t key_pitch[7] = { 0, 2, 4, 5, 7, 9, 11 };
    for (int i = 0; i < hammer_keynum(); i++) {
        if (hammer_updated(i)) {
            bool on = hammer_pressed(i);
            uint16_t vel = hammer_velocity(i);
            uint8_t note = 36 + (i / 7) * 12 + key_pitch[i % 7];

            if (vel <= 0) {
                vel = 1;
            }
            if (vel > 127) {
                vel = 127;
            }

            uint8_t packet[3] = { on ? 0x90 : 0x80, note, vel };
            tud_midi_stream_write(0, packet, 3);
        }
    }
}

static void core0_loop()
{
    uint64_t next_frame = 0;
    while(1) {
        tud_task();
        cli_run();

        savedata_loop();
        hammer_update();
        proc_midi();
        button_update();
        hid_update();
        setup_update();

        cli_fps_count(0);
        sleep_until(next_frame);
        next_frame += 250;
    }
}

/* if certain key pressed when booting, enter update mode */
static void update_check()
{
    const uint8_t pins[] = BUTTON_DEF;
    for (int i = 0; i < count_of(pins); i++) {
        uint8_t gpio = pins[i];
        gpio_init(gpio);
        gpio_set_function(gpio, GPIO_FUNC_SIO);
        gpio_set_dir(gpio, GPIO_IN);
        gpio_pull_up(gpio);
    }

    if (!gpio_get(pins[0]) && !gpio_get(pins[1])) {
        sleep_ms(100);
        reset_usb_boot(0, 2);
        return;
    }
}

void init()
{
    sleep_ms(50);
    board_init();

    update_check();

    set_sys_clock_khz(166000, true);

    tusb_init();
    stdio_init_all();

    config_init();
    mutex_init(&core1_io_lock);
    savedata_init(0xca44caa1, &core1_io_lock);

    light_init();
    hammer_init();
    button_init();

    cli_init("nos_pico>", "\n   << Nos Pico Controller >>\n"
                            " https://github.com/whowechina\n\n");
    
    commands_init();
}

int main(void)
{
    init();
    multicore_launch_core1(core1_loop);
    core0_loop();
    return 0;
}

// Invoked when received GET_REPORT control request
// Application must fill buffer report's content and return its length.
// Return zero will cause the stack to STALL request
uint16_t tud_hid_get_report_cb(uint8_t itf, uint8_t report_id,
                               hid_report_type_t report_type, uint8_t *buffer,
                               uint16_t reqlen)
{
    printf("Get from USB %d-%d\n", report_id, report_type);
    return 0;
}

// Invoked when received SET_REPORT control request or
// received data on OUT endpoint ( Report ID = 0, Type = 0 )
void tud_hid_set_report_cb(uint8_t itf, uint8_t report_id,
                           hid_report_type_t report_type, uint8_t const *buffer,
                           uint16_t bufsize)
{
    if (report_id == REPORT_ID_LIGHT_A) {
        if (bufsize < 3) {
            return;
        }
        light_set_logo(rgb32(buffer[0], buffer[1], buffer[2], false), true);
        if (bufsize < 45) {
            return;
        }
        for (int i = 0; i < 14; i++) {
            const uint8_t *rgb = buffer + i * 3 + 3;
            light_set_key(i, rgb32(rgb[0], rgb[1], rgb[2], false), true);
        }
    } else if (report_id == REPORT_ID_LIGHT_B) {
        if (bufsize < 42) {
            return;
        }
        for (int i = 0; i < 14; i ++) {
            const uint8_t *rgb = buffer + i * 3;
            light_set_key(i + 14, rgb32(rgb[0], rgb[1], rgb[2], false), true);
        }
    } else {
        printf("Set from USB %d-%d\n", report_id, report_type);
    }
}

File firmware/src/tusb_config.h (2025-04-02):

/*
 * The MIT License (MIT)
 *
 * Copyright (c) 2019 Ha Thach (tinyusb.org)
 *
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
 */

#ifndef _TUSB_CONFIG_H_
#define _TUSB_CONFIG_H_

#ifdef __cplusplus
extern "C" {
#endif

//--------------------------------------------------------------------
// COMMON CONFIGURATION
//--------------------------------------------------------------------

// defined by board.mk
#ifndef CFG_TUSB_MCU
#error CFG_TUSB_MCU must be defined
#endif

// RHPort number used for device can be defined by board.mk, default to port 0
#ifndef BOARD_DEVICE_RHPORT_NUM
#define BOARD_DEVICE_RHPORT_NUM 0
#endif

// RHPort max operational speed can defined by board.mk
// Default to Highspeed for MCU with internal HighSpeed PHY (can be port
// specific), otherwise FullSpeed
#ifndef BOARD_DEVICE_RHPORT_SPEED
#if (CFG_TUSB_MCU == OPT_MCU_LPC18XX || CFG_TUSB_MCU == OPT_MCU_LPC43XX ||   \
     CFG_TUSB_MCU == OPT_MCU_MIMXRT10XX || CFG_TUSB_MCU == OPT_MCU_NUC505 || \
     CFG_TUSB_MCU == OPT_MCU_CXD56)
#define BOARD_DEVICE_RHPORT_SPEED OPT_MODE_HIGH_SPEED
#else
#define BOARD_DEVICE_RHPORT_SPEED OPT_MODE_FULL_SPEED
#endif
#endif

// Device mode with rhport and speed defined by board.mk
#if BOARD_DEVICE_RHPORT_NUM == 0
#define CFG_TUSB_RHPORT0_MODE (OPT_MODE_DEVICE | BOARD_DEVICE_RHPORT_SPEED)
#elif BOARD_DEVICE_RHPORT_NUM == 1
#define CFG_TUSB_RHPORT1_MODE (OPT_MODE_DEVICE | BOARD_DEVICE_RHPORT_SPEED)
#else
#error "Incorrect RHPort configuration"
#endif

#ifndef CFG_TUSB_OS
#define CFG_TUSB_OS OPT_OS_NONE
#endif

// CFG_TUSB_DEBUG is defined by compiler in DEBUG build
// #define CFG_TUSB_DEBUG           0

/* USB DMA on some MCUs can only access a specific SRAM region with restriction
 * on alignment. Tinyusb use follows macros to declare transferring memory so
 * that they can be put into those specific section. e.g
 * - CFG_TUSB_MEM SECTION : __attribute__ (( section(".usb_ram") ))
 * - CFG_TUSB_MEM_ALIGN   : __attribute__ ((aligned(4)))
 */
#ifndef CFG_TUSB_MEM_SECTION
#define CFG_TUSB_MEM_SECTION
#endif

#ifndef CFG_TUSB_MEM_ALIGN
#define CFG_TUSB_MEM_ALIGN __attribute__((aligned(4)))
#endif

//--------------------------------------------------------------------
// DEVICE CONFIGURATION
//--------------------------------------------------------------------

#ifndef CFG_TUD_ENDPOINT0_SIZE
#define CFG_TUD_ENDPOINT0_SIZE 64
#endif

//------------- CLASS -------------//
#define CFG_TUD_HID 1
#define CFG_TUD_CDC 1
#define CFG_TUD_MSC 0
#define CFG_TUD_MIDI 1
#define CFG_TUD_VENDOR 0

#define CFG_TUD_VENDOR            0

// HID buffer size Should be sufficient to hold ID (if any) + Data
#define CFG_TUD_HID_EP_BUFSIZE    64

// CDC FIFO size of TX and RX
#define CFG_TUD_CDC_RX_BUFSIZE   (TUD_OPT_HIGH_SPEED ? 512 : 128)
#define CFG_TUD_CDC_TX_BUFSIZE   (TUD_OPT_HIGH_SPEED ? 512 : 128)

// CDC Endpoint transfer buffer size, more is faster
#define CFG_TUD_CDC_EP_BUFSIZE   (TUD_OPT_HIGH_SPEED ? 512 : 128)

// MIDI FIFO size of TX and RX
#define CFG_TUD_MIDI_RX_BUFSIZE   (TUD_OPT_HIGH_SPEED ? 512 : 64)
#define CFG_TUD_MIDI_TX_BUFSIZE   (TUD_OPT_HIGH_SPEED ? 512 : 64)

#ifdef __cplusplus
}
#endif

#endif /* _TUSB_CONFIG_H_ */

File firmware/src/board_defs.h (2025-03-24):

/*
 * Nos Controller Board Definitions
 * WHowe <github.com/whowechina>
 */

#if defined BOARD_NOS_PICO

#define RGB_PIN_KEY 2
#define RGB_PIN_LOGO 0
#define RGB_ORDER GRB // or RGB

#define ADC_MUX_CS 17
#define ADC_MUX_WR 16
#define ADC_MUX_A0 22
#define ADC_MUX_A1 21
#define ADC_MUX_A2 20
#define ADC_MUX_A3 19
#define ADC_MUX_A4 18

#define ADC_CHANNEL 0

#define ADC_KEY_CHN { 0, 1, 2, 3, 4, 5, 6, 7, 8, 9, 10, 11, 12, 13, 14, 15, \
                     27, 26, 25, 24, 23, 22, 21, 20, 19, 18, 17, 16 }

#define BUTTON_DEF { 13, 12, 10, 11 }
#else

#endif

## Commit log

2025-02-28 Initial upload
    [logo.dxf]
2025-02-28 PCB work just started
    [ADG732BSUZ.step, EVQ-P1D05M.stp, J 2835.step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]
2025-02-28 Change PCB folder
    [ADG732BSUZ.step, EVQ-P1D05M.stp, J 2835.step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]
2025-02-28 PCB progress 60%
    [nos_main.kicad_pcb, nos_main.kicad_sch]
2025-03-01 PCB progress 80%
    [nos_main.kicad_pcb, nos_main.kicad_sch]
2025-03-01 PCB v1.0 done
    [nos_main.kicad_pcb, nos_main.kicad_sch]
2025-03-12 PCB v1.1 for dual USB port
    [nos_main.kicad_pcb, nos_main.kicad_sch]
2025-03-13 PCB v1.11 fix housing interference
    [nos_main.kicad_pcb]
2025-03-14 Better velocity calculation
2025-03-15 Calibrate hall sensor rigin and debug
2025-03-15 Fix velocity sensitive light
    [main.c]
2025-03-19 Nos Pico Plus begins
    [ADG732BSUZ.step, EVQ-P1D05M.stp, J 2835.step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]
2025-03-20 Nos Pico PCB v1.12 (isolate vbus)
    [nos_main.kicad_pcb, nos_main.kicad_sch]
2025-03-21 Nos Pico+ PCB v1.0
    [Kailh Polia.step, Nos Plus.dxf, nos_plus.kicad_pcb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]
2025-03-24 Button support and faster clock/fps
2025-03-24 Better velocity with the help of faster fps
2025-03-24 Button in HID report
2025-03-28 PCB project update
    [Kailh Polia.step, Kailh_polia_mod.step, nos_main.kicad_pcb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]
2025-03-28 Upload 3D Print files
    [Nos Pico - Key.3mf, Nos Pico - Panel Center.3mf, Nos Pico - Panel Left.stl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]
2025-03-28 Faster sample rate
2025-03-28 Remain at 4k sample rate for consistency
2025-04-02 Nos Pico + PCB v1.01 (footprint finetune)
    [nos_plus.kicad_pcb, nos_plus.kicad_sch]
2025-04-03 Nos Pico PCB v1.2 (add buttons)
    [nos_main.kicad_pcb, nos_main.kicad_sch]
2025-04-03 Better button holes for Nos Pico
    [Nos Pico - Panel Left.stl, Nos Pico - Panel Right.stl]
2025-04-04 Minor change may help the power ripple
2025-10-12 Update stainless steel wire option
2025-10-16 Sensor runtime debug
2025-10-16 PCB v1.2, remove unnecessary components
    [nos_plus.kicad_pcb, nos_plus.kicad_sch]
2026-03-09 Shaft-end wobble elimination
    [Nos Pico - Rear Left.stl, Nos Pico - Rear Right.stl, Nos Pico+ - Rear Left.stl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]
2026-08-28 Update guide for newer PCB revisions
